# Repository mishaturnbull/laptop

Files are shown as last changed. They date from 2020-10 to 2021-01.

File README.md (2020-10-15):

# Laptop build project

* Motherboard: Udoo Bolt V8
  * Ryzen Embedded V1605B:
    * 4 core/8 thread @ 2.0GHz (max 3.6GHz)
    * Radeon Vega 8 (8 GPU CU)
* RAM: 2xDDR4 dual-channel SODIMM, upgradeable to 32GB (ECC supported)
* Supported OS: Any x86-compatible OS
  * Tested: Windows 10, Ubuntu, Kali Linux
  * Bootable from USB, onboard storage, network
* Storage:
  * 32GB eMMC onboard
  * 1x NVMe M.2 2280
  * 1x M.2 SATA 2260
  * 1x SATA 3.0 6Gb/s standard connector

# Use & reproduction permissions

This repository is licensed under the MIT license.  The only thing I ask is
that if you're going to make one, email me.  I'm curious about how many of
these machines there are going to be.

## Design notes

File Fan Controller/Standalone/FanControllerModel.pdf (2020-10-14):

%[lowC, highC, offset, scale V/C, V @ 25C] TMP35 = [10, 125, 0, .01, .25];
TMP36 = [-40, 125, 0.5, .01, .75];
TMP37 = [5, 100, 0, .02, .5];
%T = (V-offset)/scale
%range = .1 to 2V
%50 uA output. Short = 250 uA. %[Vgs(off), Vgs(on)]
FQP = [1,2.5];

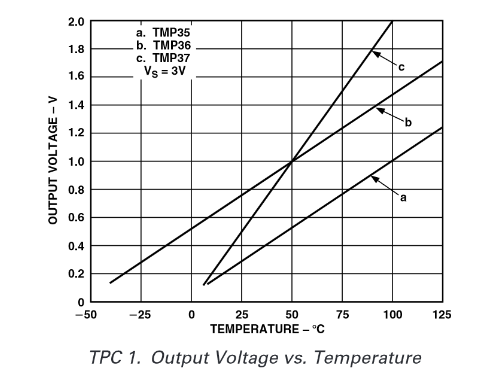
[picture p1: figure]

%TMP35:
off = (FQP(1)-TMP35(3))/TMP35(4)

off = 100
on = (FQP(2)-TMP35(3))/TMP35(4)

on = 250

%TMP36:
off = (FQP(1)-TMP36(3))/TMP36(4)

1

off = 50
on = (FQP(2)-TMP36(3))/TMP36(4)

on = 200

%TMP37:
off = (FQP(1)-TMP37(3))/TMP37(4)

off = 50
on = (FQP(2)-TMP37(3))/TMP37(4)

on = 125

2

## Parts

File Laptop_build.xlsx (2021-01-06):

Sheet: Parts
Part | Name | Link | Price per | Quantity | Price total | Power draw (A) | Power supply (V) | Watt total | Weight (g) | Weight total
Motherboard | Udoo Bolt V8 | https://www.udoo.org/udoo-bolt/ | $418.00 | 1 | $418.00 | 3.15 | 19 | 59.85 | 117 | 117
RAM 16GB | Crucial 8GBx2 2400MHz | https://www.amazon.com/Crucial-16GBx2-PC4-19200-SODIMM-260-Pin/dp/B019FRDAY6?s=gateway | $63.99 | 1 | $63.99 |  | 1.2 | 0 | 18.14 | 18.14
SSD 1TB | Crucial P1 | https://www.amazon.com/Crucial-1TB-NAND-NVMe-PCIe/dp/B07J2Q4SWZ?s=gateway | $99.95 | 1 | $99.95 | 1.7 | 3.3 | 5.61 | 18.14 | 18.14
HDD 1TB | Toshiba MQ01ABD | https://www.amazon.com/dp/B009AYVNMQ/?coliid=I35V6HECAOKQSW&colid=2LUIJZIICRMNA | $43.99 | 1 | $43.99 | 5 | 1 | 5 | 9.07 | 9.07
2KVM | 2 Port KVM HDMI | https://www.amazon.com/dp/B00FSARCX0/?coliid=I16WQOKDSD9YRY&colid=2LUIJZIICRMNA | $76.19 | 1 | $76.19 |  |  | 0 | 12.6 | 12.6
Qwiic cable kit | Qwiic cable kit | https://www.amazon.com/Electronics123-SparkFun-Qwiic-Cable-Kit/dp/B07ML9BMXX?s=gateway | $15.35 | 1 | $15.35 | 0 | 0 | 0 |  | 0
Fingerprint reader | SF 14518 | https://www.amazon.com/dp/B07BHPZL11/?coliid=I1FC7WEQA7ZYF9&colid=2LUIJZIICRMNA | $38.95 | 1 | $38.95 |  |  | 0 | 18.14 | 18.14
10DoF IMU | MPU9250+BMP180 | https://wiki.seeedstudio.com/Grove-IMU_10DOF/ | $16.90 | 1 | $16.90 | 0.00393 | 3.3 | 0.012969 |  | 0
GNSS | SAM-M8Q Breakout | https://www.sparkfun.com/products/15210 | $39.95 | 1 | $39.95 | 0.029 | 3.3 | 0.0957 |  | 0
Battery packs | 5Ah 11.1V 3S LiPo x2 | https://www.amazon.com/dp/B072WQ6FNP/?coliid=I3MOC6L9HG307I&colid=2LUIJZIICRMNA | $74.89 | 2 | $149.78 |  |  | 0 | 753 | 1506
Protoboard pack | 32pc 2-side PCB proto | https://www.amazon.com/ELEGOO-Prototype-Soldering-Compatible-Arduino/dp/B072Z7Y19F?s=industrial | $9.99 | 1 | $9.99 | 0 | 0 | 0 |  | 0
Breadboard pack | Breadboard + zipwire | https://www.amazon.com/BreadBoard-ZipWire-Solderless-ZW-MM-10-ZipWires/dp/B00PKKPSCU?s=industrial | $8.90 | 1 | $8.90 | 0 | 0 | 0 |  | 0
USB3 Hub | Anker 4-port | https://www.amazon.com/Anker-Extended-MacBook-Surface-Notebook/dp/B07L32B9C2?s=gateway | $7.99 | 1 | $7.99 | 0 | 0 | 0 | 18.14 | 18.14
Keyboard | Periboard-426 | https://www.amazon.com/gp/product/B087679W1N?psc=1 | $19.99 | 1 | $19.99 | 0.3 | 5 | 1.5 | 381 | 381
Numpad | DFMicro USB Numpad | https://www.amazon.com/gp/product/B0872XMZ4M?psc=1 | $7.99 | 1 | $7.99 | 0.25 | 5 | 1.25 | 120 | 120
Touchpad | Keymecher Mano | https://www.amazon.com/Keymecher-Multi-Gesture-Trackpad-Touchpad-Precision/dp/B085SVLH95 | $39.99 | 1 | $39.99 |  | 5 | 0 | 91 | 91
Screen 15.6in | ZSCMALLS 15.6” | https://www.amazon.com/ZSCMALLS-Portable-Computer-Nintendo-Raspberry/dp/B07VFF4TZG | $129.99 | 1 | $129.99 | 3 | 5 | 15 | 644 | 644
USB-C cable | USB-C 1.5ft x2 | https://www.amazon.com/Besgoods-Charging-Braided-Compatible-Nintendo/dp/B07H24V7YJ?s=pc | $8.59 | 1 | $8.59 | 0 | 0 | 0 | 40.82 | 40.82
WiFi/BT | Kit M.2 WiFi/Bt | https://shop.udoo.org/kit-m2-wifi-bt.html | $16.90 | 1 | $16.90 |  |  | 0 | 8.5 | 8.5
USB-C extension | USB-C 3.1 extension x2 | https://www.amazon.com/RIITOP-Extender-Extension-Nintendo-Macbook/dp/B07NSXGM7F?s=aht | $15.99 | 1 | $15.99 | 0 | 0 | 0 | 22.7 | 22.7
Ethernet extension | 1ft patch cable | https://www.amazon.com/Monoprice-Flexboot-Ethernet-Patch-Cable/dp/B00AJHCMG4?s=gateway | $2.22 | 1 | $2.22 | 0 | 0 | 0 | 18.14 | 18.14
Ethernet coupler | RJ45 coupler 10Gb | https://www.amazon.com/Haitronic-ethernet-Connector-Ethernet-Extender/dp/B06XPZBRJ2/136-8664393-2449817 | $6.99 | 1 | $6.99 | 0 | 0 | 0 | 22.7 | 22.7
Cooling fan | Mini 5V cooling fan | https://www.adafruit.com/product/3368 | $3.50 | 3 | $10.50 | 0.2 | 5 | 3 | 6.2 | 18.6
Temperature sensor | TMP36 | https://www.digikey.com/en/products/detail/analog-devices-inc/TMP36GT9Z/820404 | $1.48 | 4 | $5.92 | 0.0001 | 5 | 0.002 |  | 0
Total |  |  |  | 30 | $1255.00 | 13.63303 | 19 | 91.320669 |  | 3084.69

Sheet: Cooling
Fluid options
Brand | Name | Thermal Cap
3M | Fluorinert |  | https://multimedia.3m.com/mws/media/1783283O/data-center-immersion-cooling-aplications-with-3m-fluorinert-electronic-liquids-line-card.pdf
3M | Novec |  | https://multimedia.3m.com/mws/media/1801351O/data-center-immersion-cooling-aplications-with-3m-novec-engineered-fluids-line-card.pdf
Xoxide | PC-ICE |  | http://www.xoxide.com/primoice-nonconductive-fluid-clear.html
NA | distilled water | 4
NA | mineral oil | 1.6

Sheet: BatteryReqs
Per Battery Pack |  |  |  | N. Battery Packs |  | Power system available |  |  | Life expectancy
N. 18650 | 8 | Output V | 14 | Series | 1 | Total Wh | 154 |  | Power draw (from Parts sheet), W | 84.319169
V/cell | 3.5 | Max A | 5.5 | Parallel | 2 | Total mAh | 11000 |  | Time to death (h) | 1.826393711
mAh/cell | 2750 | Max W | 77 |  |  | Input V | 14 |  | Available power (W) | 154
Series | 4 | mAh | 5500 |  |  | Max A | 11
Parallel | 2 | Wh | 77
C rating | 1
 |  |  |  |  |  | Watt-amp avail & draw
 |  |  |  |  |  | Rail voltage | Avail (A) | Draw (A) | Draw (W)
 |  |  |  |  |  | 3.3 | 46.66666667 | 1.73293 | 5.718669
 |  |  |  | Only input on this color! |  | 5 | 30.8 | 3.7501 | 18.7505
 |  |  |  |  |  | 19 | 8.105263158 | 3.15 | 59.85
 |  |  | WARNING: THIS SPREADSHEET IS LIKELY WRONG. I am not an electrical engineer, and it has not (yet) been looked over by one! Some of the formulas are KNOWN TO BE INCORRECT!

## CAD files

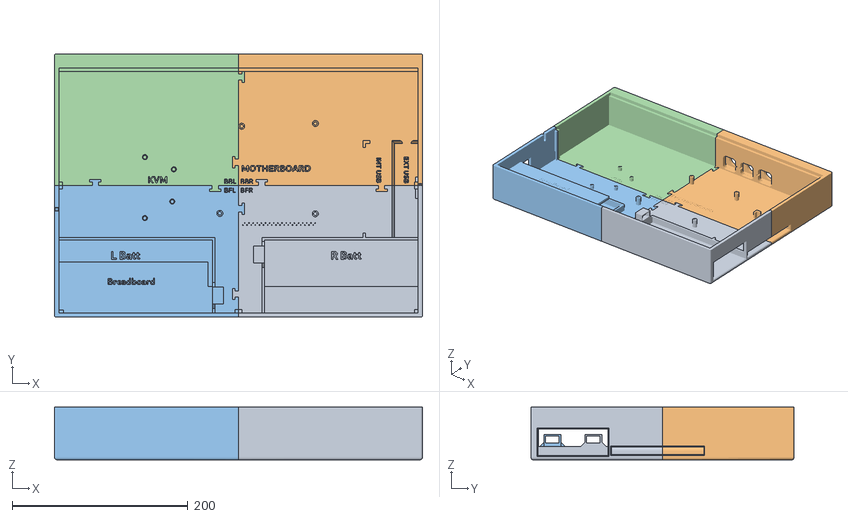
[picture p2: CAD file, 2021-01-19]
cad/case.obj
419.0 x 300.0 x 60.0
bottom-front-right
bottom-back-right
bottom-front-left
bottom-back-left

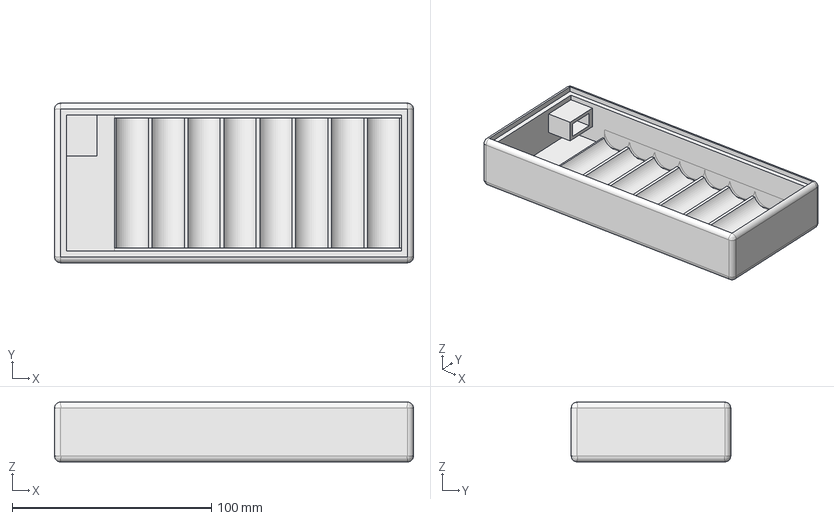
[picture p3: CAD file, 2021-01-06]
cad/battpack.FCStd
180.0 x 80.0 x 30.0 mm

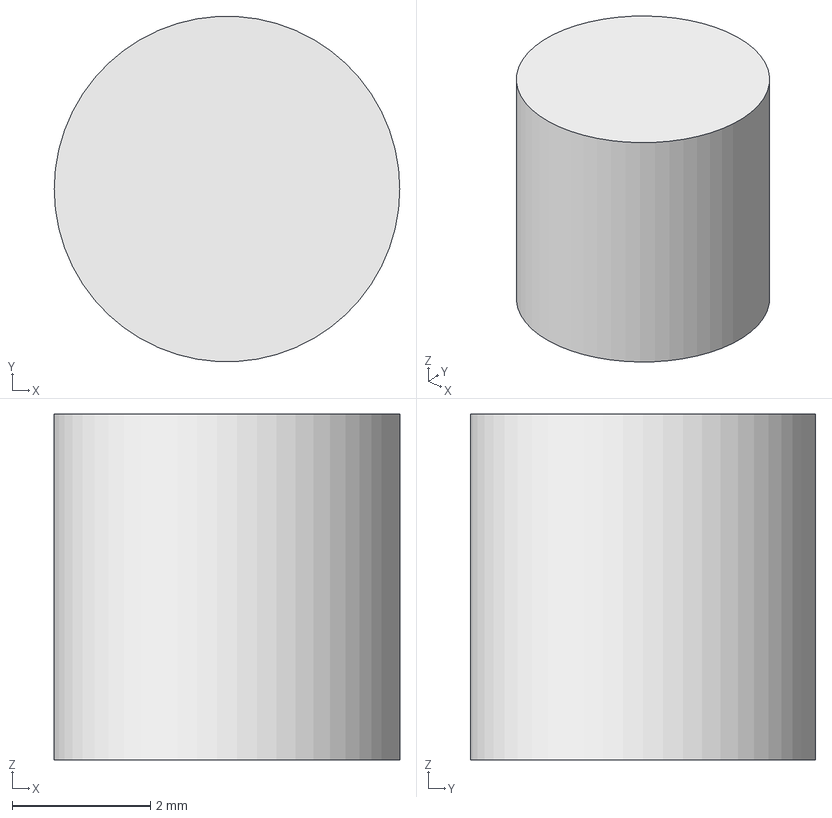
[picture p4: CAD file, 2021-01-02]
cad/vert-hold-pin-2.FCStd
5.00 x 4.99 x 5.00 mm

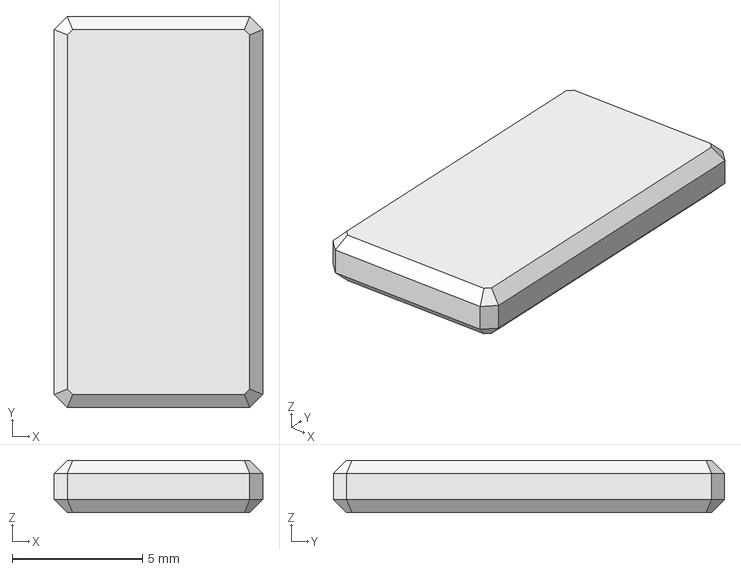
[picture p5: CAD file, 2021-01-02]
cad/vert-hold-pin-1.FCStd
8.00 x 15.0 x 2.00 mm

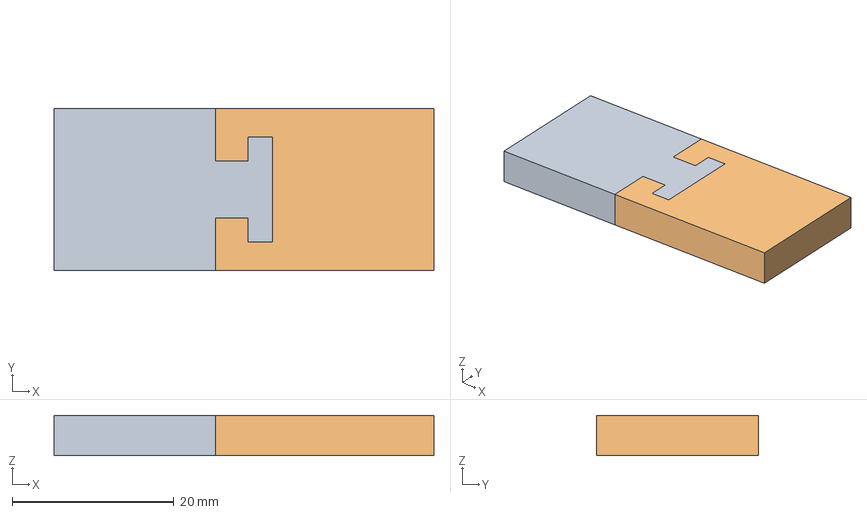
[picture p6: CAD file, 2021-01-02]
cad/tjoint-strength-test.FCStd
47.0 x 20.0 x 5.00 mm
male
female

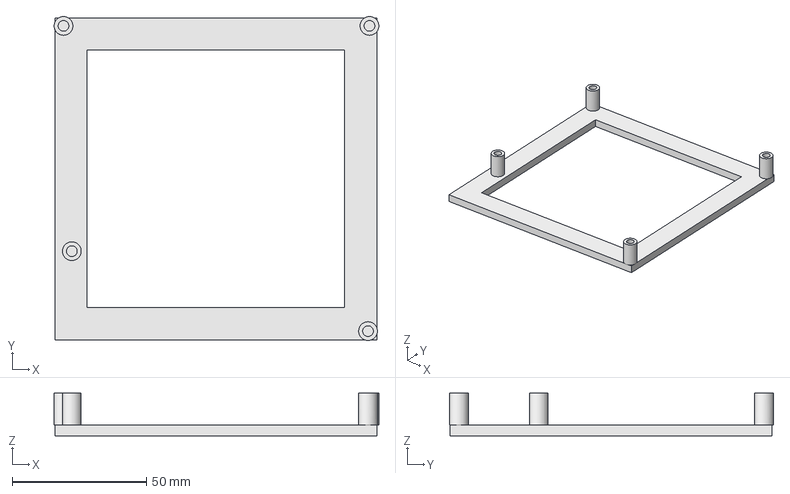
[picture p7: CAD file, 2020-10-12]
cad/caseless-bolt-holder.FCStd
121.0 x 120.8 x 16.0 mm

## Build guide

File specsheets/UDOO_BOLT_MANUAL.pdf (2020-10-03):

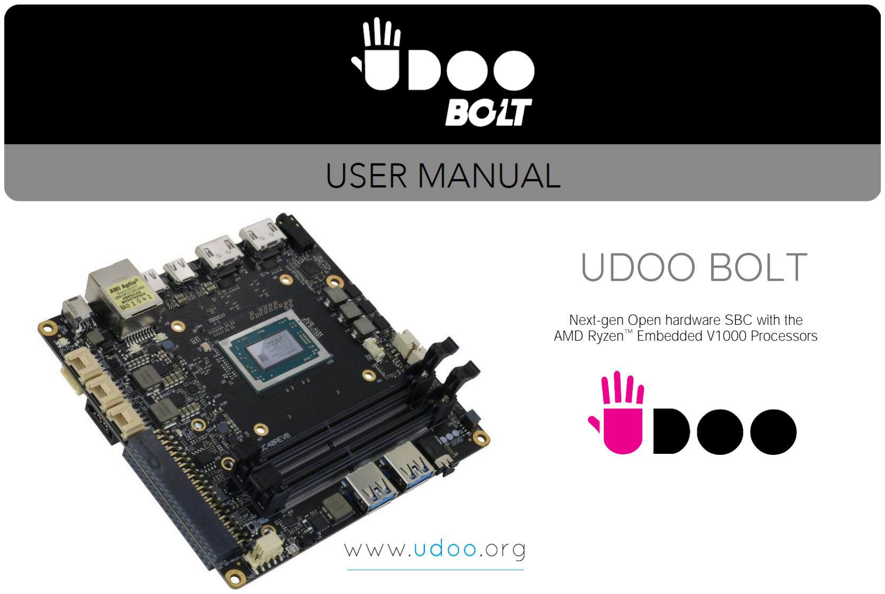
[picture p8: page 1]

# UDOO BOLT

### Next-gen Open hardware SBC with the AMD Ryzen Embedded V1000 Processors

## BOLT

UDOO BOLT User Manual - Rev. First Edition: 1.0 - Last Edition: 1.0 - Author: S.B. - Reviewed by L.V. Copyright © 2019 SECO S.p.A. | 2

This manual is released under Creative Commons Attribution-NonCommercial-ShareAlike 4.0 International (CC BY-NC-SA 4.0) license (https://creativecommons.org/licenses/by-nc-sa/4.0/)
Every effort has been made to ensure the accuracy of this manual. However, SECO S.p.A. accepts no responsibility for any inaccuracies, errors or omissions herein. SECO S.p.A. reserves the right to change precise specifications without prior notice to supply the best product possible.
To get the required assistance for any and possible issues, please contact us using the dedicated web form available at http://www.udoo.org/customer-care/open.php. (http://www.udoo.org/customer-care/open.php)
Our team is ready to assist.
Revision | Date | Note | Ref
1.0 | 19 April 2019 | First Official Release. | SB
1.1 | 11 September 2019

Matching between commercial names and ordering codes added; Safety and certifications paragraph 1.4 updated
Labels paragraph 1.7 added
Typo corrected in par. 4.6

SB

## REVISION HISTORY

Throughout all this document the commercial names: UDOO BOLT V3 and UDOO BOLT V8 will refer, respectively, to the ordering codes P/N SC40-1000-0000-C0 and SC40-2000-0000-C0 will be called with

UDOO BOLT User Manual - Rev. First Edition: 1.0 - Last Edition: 1.0 - Author: S.B. - Reviewed by L.V. Copyright © 2019 SECO S.p.A. | 3

## INDEX

UDOO BOLT User Manual - Rev. First Edition: 1.0 - Last Edition: 1.0 - Author: S.B. - Reviewed by L.V. Copyright © 2019 SECO S.p.A. | 4

UDOO BOLT User Manual - Rev. First Edition: 1.0 - Last Edition: 1.0 - Author: S.B. - Reviewed by L.V. Copyright © 2019 SECO S.p.A. | 5

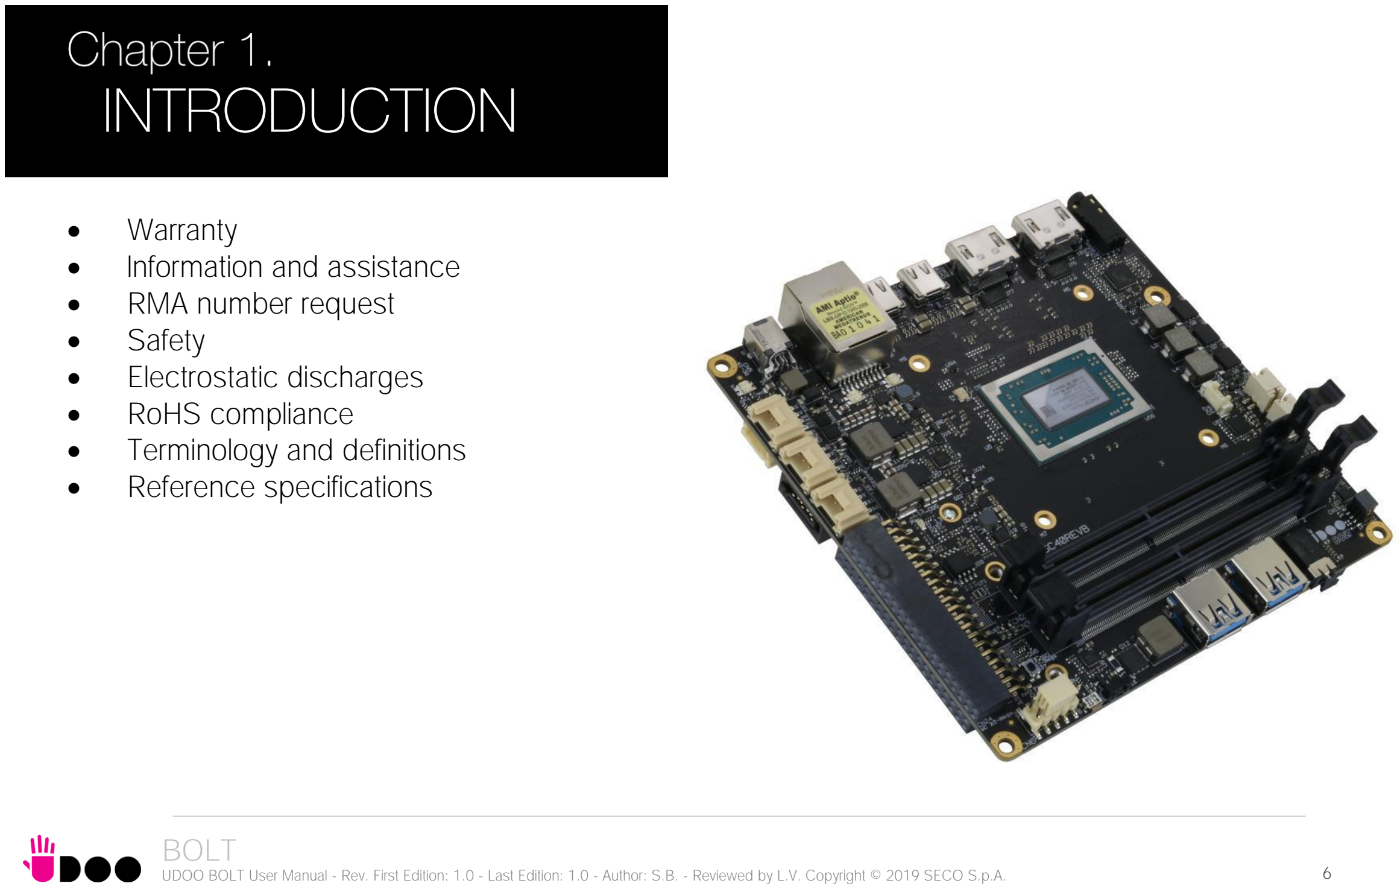
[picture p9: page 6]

UDOO BOLT User Manual - Rev. First Edition: 1.0 - Last Edition: 1.0 - Author: S.B. - Reviewed by L.V. Copyright © 2019 SECO S.p.A. | 6

## - Warranty - Information and assistance - RMA number request - Safety - Electrostatic discharges - RoHS compliance - Terminology and definitions - Reference specifications

UDOO BOLT User Manual - Rev. First Edition: 1.0 - Last Edition: 1.0 - Author: S.B. - Reviewed by L.V. Copyright © 2019 SECO S.p.A. | 7

## 1.1 Warranty

This product is subject to the Italian Law Decree 24/2002, acting European Directive 1999/44/CE on matters of sale and warranties to consumers.
The warranty on this product lasts for 2 years.
Under the warranty period, the Supplier guarantees the buyer assistance and service for repairing, replacing or credit of the item, at the Supplier’s own discretion. Items cannot be returned unless previously authorized by the supplier.
The authorization is released after completing the specific form available on the web-site http://www.udoo.org/customer-care/ (Open a New Ticket → Return Merchandise Application). The RMA authorization number must be put both on the packaging and on the documents shipped with the items, which must include all the accessories in their original packaging, with no signs of damage to, or tampering with, any returned item.
The error analysis form identifying the fault type must be completed by the customer and has must accompany the returned item.
Following a technical analysis, the supplier will verify if all the requirements, for which a warranty service applies, are met. If the warranty cannot be applied, the Supplier will calculate the minimum cost of this initial analysis on the item and the repair costs. Costs for replaced components will be calculated separately.

All changes or modifications to the equipment not explicitly approved by SECO S.p.A. could impair the equipment’s functionalities and could

UDOO BOLT User Manual - Rev. First Edition: 1.0 - Last Edition: 1.0 - Author: S.B. - Reviewed by L.V. Copyright © 2019 SECO S.p.A. | 8

## 1.2 Information and assistance

What do I have to do if I’m experiencing problems with my product?

The following services are available:
- UDOO website: visit http://www.udoo.org to receive the latest information on the product. In most cases it is possible to find useful information to solve the problem.
- UDOO Forum: join to the community of UDOO users. In the forum, available at http://www.udoo.org/forum/, it is possible to search the multiple topics of the community, and look for other users that had the same kind of problem - and how they solved it. It is also possible to post new topics to ask for specific help.
- Repair centre: it is possible to send the faulty product to the SECO Repair Centre. In this case, follow this procedure:
- Returned items must be accompanied by a RMA Number. Items sent without the RMA number will be not accepted.
- Returned items must be shipped in an appropriate package. SECO is not responsible for damages caused by accidental drop, improper usage, or customer neglect.
Note: Please have the following information before asking for technical assistance:
- Name and serial number of the product;
- Description of Customer’s peripheral connections;
- Description of Customer’s software (operating system, version, application software, etc.);
- A complete description of the problem;
- The exact words of every kind of error message encountered.

## 1.3 RMA number request

To request a RMA number, please visit UDOO web-site. On the bottom of the page, please select “Customer Care”, click on the “Open a New ticket” button and. A RMA Number will be sent within 1 working day (only for on-line RMA requests).

UDOO BOLT User Manual - Rev. First Edition: 1.0 - Last Edition: 1.0 - Author: S.B. - Reviewed by L.V. Copyright © 2019 SECO S.p.A. | 9

## 1.4 Safety and certifications

The UDOO BOLT board uses only extremely-low voltages.
While handling the board, please use extreme caution to avoid any kind of risk or damages to electronic components.

CE and FCC certification retained using only the UDOO BOLT qualified Power Supply Unit. When not using UDOO BOLT qualified Power Supply, use 19VDC (min 60W power) PSUs certified for your country (make sure that the power cable is less than 3 mt. long).
UDOO BOLT qualified PSU: YS50-1903150. Input: 100-240VAC 50/60Hz. Output: 19VDC 3.15A 65WMax
CE and FCC certifications retained with the board inside the UDOO BOLT metal case. When not available, it is suggested to use a case with the same attributes as the UDOO BOLT metal Case (P/N: ENCLOSURE_BOLT).
The UDOO BOLT V3 (P/N: SC40-1000-0000-C0) and UDOO BOLT V8 (P/N SC40-2000-0000-C0) are part of the KIT_UDOO_BOLT_V3 and KIT_UDOO_BOLT_V8 can be sold individually as a spare part allowing the end user to replace the board inside the Enclosure.

## 1.5 Electrostatic discharges

The UDOO BOLT board, like any other electronic product, is an electrostatic sensitive device: high voltages caused by static electricity could damage some or all the devices and/or components on-board.

This product should be operated in a well-ventilated environment and, if used inside a case, the case should not be covered.
This product should be elevated on a stable, flat, electrically non-conductive surface whilst in operation, and clear from any object that can induce a short-circuit.
Do not expose it to water, moisture or heat from any source; UDOO BOLT is designed for reliable operation at normal ambient room temperatures.
Avoid handling the warm and moving parts (like the fan) and generally the printed circuit board while it is powered

Only handle by the edges to minimise the risk of electrostatic discharge damage.
Take care whilst handling to avoid mechanical or electrical damage to the printed circuit board and connectors. Also use a grounded wrist strap or touch a safely grounded object before you handle components.

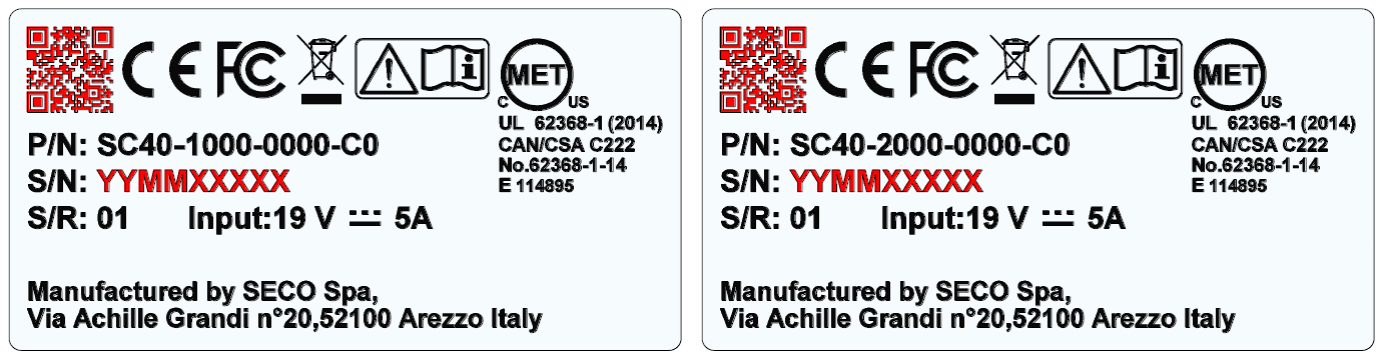
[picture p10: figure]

UDOO BOLT User Manual - Rev. First Edition: 1.0 - Last Edition: 1.0 - Author: S.B. - Reviewed by L.V. Copyright © 2019 SECO S.p.A. | 10

## 1.6 RoHS compliance

The UDOO BOLT board is designed using RoHS compliant components and is manufactured on a lead-free production line. It is therefore fully RoHS compliant.

## 1.7 Labels

The labels above depend on the board: the left one is related to the module UDOO_BOLT_V3 (P/N: SC40-1000-0000-C0) while the right label is related to the module UDOO_BOLT_V8 (P/N: SC40-2000-0000-C0).
The parts highlighted in red (the QR Code and the Serial Number) will change for every Board.
The S/N is divided in:
YY= Year of Manufacturing.
MM= Month of Manufacturing. XXXXX= Monthly Progressive Number

UDOO BOLT User Manual - Rev. First Edition: 1.0 - Last Edition: 1.0 - Author: S.B. - Reviewed by L.V. Copyright © 2019 SECO S.p.A. | 11

## 1.8 FCC certification

This device complies with part 15 of the FCC Rules. Operation is subject to the following two conditions:
(1) This device may not cause harmful interference, and
(2) this device must accept any interference received, including interference that may cause undesired operation.
This equipment has been tested and found to comply with the limits for a Class B digital device, pursuant to part 15 of the FCC Rules. These limits are designed to provide reasonable protection against harmful interference in a residential installation. This equipment generates, uses and can radiate radio frequency energy and, if not installed and used in accordance with the instructions, may cause harmful interference to radio communications. However, there is no guarantee that interference will not occur in a particular installation. If this equipment does cause harmful interference to radio or television reception, which can be determined by turning the equipment off and on, the user is encouraged to try to correct the interference by one or more of the following measures:
Reorient or relocate the receiving antenna.
Increase the separation between the equipment and receiver.
Connect the equipment into an outlet on a circuit different from that to which the receiver is connected. Consult the dealer or an experienced radio/TV technician for help.

To comply with FCC RF exposure compliance requirements, a separation distance of at least 20 cm must be maintained between th e antenna of this device and all nearby persons.

FCC certification retained using only the UDOO BOLT qualified Power Supply Unit (19V Brick Power Adapter). When not using UDOO BOLT qualified Power Supply, use 19VDC (min 60W power) PSUs certified for your country (make sure that the power cable is less than 3 mt. long).

SECO S.p.A.
Model: UDOO BOLT V3; UDOO BOLT V8

Changes or modifications not expressly approved by the party responsible for compliance could void the user’s authority to operate the

UDOO BOLT User Manual - Rev. First Edition: 1.0 - Last Edition: 1.0 - Author: S.B. - Reviewed by L.V. Copyright © 2019 SECO S.p.A. | 12

## 1.9 ISED certification

This device complies with Industry Canada licence-exempt RSS standard(s). Operation is subject to the following two conditions:
(1) This device may not cause interference
(2) this device must accept any interference, including interference that may cause undesired operation of the device.

Le présent appareil est conforme aux CNR d’Industrie Canada applicables aux appareils radio exempts de licence. L’exploitation est autorisée aux deux conditions suivantes:
(1) l’appareil ne doit pas produire de brouillage, et
(2) l’utilisateur de l’appareil doit accepter tout brouillage radioélectrique subi, même si le brouillage est susceptible d’en compromettre le fonctionnement.
Ce dispositif a été conçu pour fonctionner avec les antennes fournies avec ce produit. L’utilisation d’autres antennes peut enfreindre les règles industrielles du Canada et annuler l’autorité de l’utilisateur quant au fonctionnement de l’équipement.

This device complies with RSS-210, ICES-3(B)/NMB-3(B)

UDOO BOLT User Manual - Rev. First Edition: 1.0 - Last Edition: 1.0 - Author: S.B. - Reviewed by L.V. Copyright © 2019 SECO S.p.A. | 13

## 1.10 Terminology and definitions

ACPI | Advanced Configuration and Power Interface, an open industrial standard for the board’s devices configuration and power management
AHCI | Advanced Host Controller Interface, a standard which defines the operation modes of SATA interface
API | Application Program Interface, a set of commands and functions that can be used by programmers for writing software for specific Operating Systems
BIOS | Basic Input / Output System, the Firmware Interface that initializes the board before the OS starts loading
CEC | Consumer Electronics Control, an HDMI feature which allows controlling more devices connected together by using only one remote control
DDC | Display Data Channel, a kind of I2C interface for digital communication between displays and graphics processing units (GPU)
DDR | Double Data Rate, a typology of memory devices which transfer data both on the rising and on the falling edge of the clock
DDR4 | DDR, 4 th generation
EC | Embedded Controller
GbE | Gigabit Ethernet
Gbps | Gigabits per second
GND | Ground
GPI/O | General purpose Input/Output
HD Audio | High Definition Audio, most recent standard for hardware codecs developed by Intel® in 2004 for higher audio quality
HDMI | High Definition Multimedia Interface, a digital audio and video interface
I2C Bus | Inter-Integrated Circuit Bus, a simple serial bus consisting only of data and clock line, with multi-master capability
M.2 | Specifications for internal expansion modules, which defines many pinouts and sizes for different purposes. Can include SATA, PCI Express, USB, UART, DP interfaces
Mbps | Megabits per second
MMC/eMMC | MultiMedia Card / embedded MMC, a type of memory card, having the same interface as the SD card. The eMMC is the embedded version of the MMC. They are devices that incorporate the flash memories on a single BGA chip.
N.A. | Not Applicable
N.C. | Not Connected
OpenCL | Open Computing Language, a software library based on C99 programming language, conceived explicitly to realise parallel computing using Graphics Processing Units (GPU)
OpenGL | Open Graphics Library, an Open Source API dedicated to 2D and 3D graphics
OS | Operating System

UDOO BOLT User Manual - Rev. First Edition: 1.0 - Last Edition: 1.0 - Author: S.B. - Reviewed by L.V. Copyright © 2019 SECO S.p.A. | 14
PCI-e | Peripheral Component Interface Express
PSU | Power Supply Unit
PWM | Pulse Width Modulation
PWR | Power
PXE | Preboot Execution Environment, a way to perform the boot from the network ignoring local data storage devices and/or the installed OS
SATA | Serial Advance Technology Attachment, a differential full duplex serial interface for Hard Disks
SD | Secure Digital, a memory card type
SDHC | Secure Digital Host Controller
SDIO | Secure Digital Input/Output, an evolution of the SD standard that allows the use of the same SD interface to drive different Input/Output devices, like cameras, GPS, Tuners and so on
SM Bus | System Management Bus, a subset of the I2C bus dedicated to communication with devices for system management, like a smart battery and other power supply-related devices
SPI | Serial Peripheral Interface, a 4-Wire synchronous full-duplex serial interface which is composed of a master and one or more slaves, individually enabled through a Chip Select line
TBM | To Be Measured
TDP | Thermal Design Power, an indication of the amount of heat generated by the processor that must be used for the design of the thermal solution.
TMDS | Transition-Minimized Differential Signaling, a method for transmitting high speed serial data, normally used on DVI and HDMI interfaces
UEFI | Unified Extensible Firmware Interface, a specification defining the interface between the OS and the board’s firmware. It is meant to replace the original BIOS interface
UMA | Unified Memory Architecture, synonym of Integrated Graphics, uses a portion of a computer’s system RAM dedicated to graphics rather than using dedicated graphics memory only.
USB | Universal Serial Bus
V_REF | Voltage reference Pin
xHCI | eXtensible Host Controller Interface, Host controller for USB 3.0 ports, which can also manage USB 2.0 and USB1.1 ports

UDOO BOLT User Manual - Rev. First Edition: 1.0 - Last Edition: 1.0 - Author: S.B. - Reviewed by L.V. Copyright © 2019 SECO S.p.A. | 15

## 1.11 Reference specifications

Here below it is a list of applicable industry specifications and reference documents.
Reference | Link
ACPI | http://www.acpi.info
AHCI | http://www.intel.com/content/www/us/en/io/serial-ata/ahci.html
DDC | http://www.vesa.org
Gigabit Ethernet | http://standards.ieee.org/about/get/802/802.3.html
HD Audio | http://www.intel.com/content/dam/www/public/us/en/documents/product-specifications/high-definition-audio-specification.pdf
HDMI | http://www.hdmi.org/index.aspx
I2C | http://www.nxp.com/documents/other/UM10204_v5.pdf
Intel® Front Panel I/O connectivity DG | http://www.formfactors.org/developer/specs/A2928604-005.pdf
M.2 | http://pcisig.com/specifications
MMC/eMMC | http://www.jedec.org/committees/jc-649
OpenCL | http://www.khronos.org/opencl
OpenGL | http://www.opengl.org
PCI Express | http://www.pcisig.com/specifications/pciexpress
SATA | https://www.sata-io.org
SD Card Association | https://www.sdcard.org/home
SM Bus | http://www.smbus.org/specs
TMDS | http://www.siliconimage.com/technologies/tmds
UEFI | http://www.uefi.org
USB 2.0 and USB OTG | http://www.usb.org/developers/docs/usb_20_070113.zip
USB 3.0 | http://www.usb.org/developers/docs/usb_30_spec_070113.zip
xHCI | http://www.intel.com/content/www/us/en/io/universal-serial-bus/extensible-host-controler-interface-usb-xhci.html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
AMD Ryzen Embedded V1000 | https://www.amd.com/en/products/embedded-ryzen-v1000-series

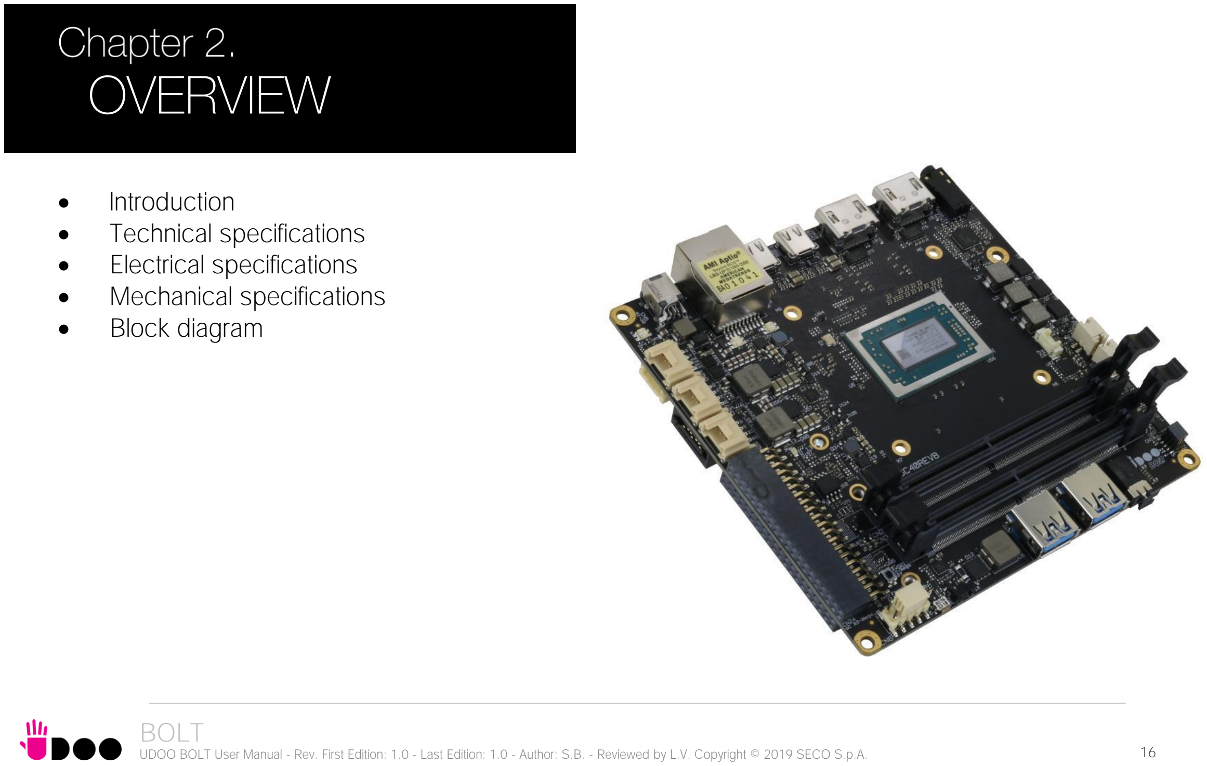
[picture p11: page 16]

UDOO BOLT User Manual - Rev. First Edition: 1.0 - Last Edition: 1.0 - Author: S.B. - Reviewed by L.V. Copyright © 2019 SECO S.p.A. | 16

## - Introduction - Technical specifications - Electrical specifications - Mechanical specifications - Block diagram

UDOO BOLT User Manual - Rev. First Edition: 1.0 - Last Edition: 1.0 - Author: S.B. - Reviewed by L.V. Copyright © 2019 SECO S.p.A. | 17

## 2.1 Introduction

The UDOO BOLT is a portable, breakthrough supercomputer that goes up to 3.6 GHz thanks to the brand-new AMD Ryzen Embedded V1000 SoC, a top-notch, multicore CPU with a powerful mobile GPU - AMD Radeon Vega 8 or AMD Radeon Vega 3 Graphics, the most incredible GPUs ever seen on a maker platform and an Arduino Leonardo compatible platform, all wrapped into one.
The UDOO BOLT can mount a Dual-Core Quad-Thread or a Quad-Core eight-thread SoCs, base frequency 2.3 or 2.0 GHz, Turbo boost at 3.2 or 3.6 GHz, with 64-bit instruction set and very low TDP. This single chip solution includes the memory controller, which gives support for up to 32GB of DDR4 memory on two SO-DIMM Slots, also capable of supporting ECC memory.
All SoCs embed an AMD Radeon Vega Graphics controller, with 3 or 8 Execution units, which offers extremely high graphical performances, supporting also High Dynamical range (HDR) Imaging. DirectX® 12, EGL 1.4, OpenCL 2.1, OpenGL® ES 1.1/ 2.x / 3.x (Halti), OpenGL® Next (Vulkan®

), OpenGL® 4.6 are also supported by this GPU, which can also offer H.265 10-bit video decoding and 8-bit encoding.
Finally, this embedded GPU is able to drive four 4K independent displays, by using the HDMI and the USB-C interfaces available.
Other features offered by the AMD Ryzen Embedded V1000 SoCs, and included in UDOO BOLT board, are two SATA Revision 3.0 Channels (one used for the common SATA / SSD drives, the other used to implement a M.2 Socket 2 Key B SSD slot), six USB ports (two USB 3.1 on standard Type-A sockets, two USB 3.1 on standard type-C sockets supporting Display Port Alternate Mode and Power Delivery functions, one USB 2.0 on M.2 Socket 1 Key E Connectivity slot and another USB 2.0 port used for the communications with the Atmega32u4 microcontroller), HD Audio and eight PCI Express lanes (two lanes are carried out on M.2 Socket 2 Key B SSD slot where they can be used as a single PCI-e x2 port, a PCI express lane is used for the implementation of the Gigabit Ethernet interface, ,another is available on M.2 Socket 1 Key E Connectivity Slot and four PCI-express Graphics lanes are carried to the M.2 Key M Slot for NVMe SSDs, where they can be used as a single PCI-e x 4 port).
Through the AMD Ryzen Embedded V1000 SoC’s USB interface #5 pass all the communications with the ATMEL ATmgea32u4 microcontroller, which implements the Arduino Leonardo interface: this situation reproduces exactly the situation of an external Arduino board connected to an x86 PC, with the advantages given by an integrated board solution.
All these features, combined together, make UDOO BOLT the most powerful maker board ever.
Please refer to following chapter for a complete list of all the integrated peripherals and the characteristics.

## 2.2 Technical specifications

SoC
AMD Ryzen Embedded V1605B with AMD Radeon Vega 8 Graphics, Quad Core Dual Thread @ 2.0GHz (3.6 Boost), TDP 12-25W
AMD Ryzen Embedded V1202B with AMD Radeon Vega 3 Graphics, Dual Core Dual Thread @ 2.3GHz (3.2 Boost), TDP 12-25W
Memory
2x DDR4 SO-DIMM Slots, supporting DDR4-2400 ECC and non-ECC memory Graphics
AMD Radeon Vega GPU with 8 (V1605B) or 3 (V1202B) Compute Units
4 independent displays supported
DirectX® 12, EGL1.4, OpenCL 2.1, OpenGL® ES 1.1/ 2.x / 3.x (Halti), OpenGL® Next (Vulkan®), OpenGL® 4.6 supported
H.265 (10-bit) decode and 8-bit video encode
VP9 decode
Video Interfaces
2x HDMI connector, supporting HDMI 1.4 / HDMI 2.0a
2x DP alternate mode interfaces on USB Type-C connectors Video Resolution
Up to 4K
Mass Storage
32GB eMMC 5.0 drive on-board
SATA 6Gb/s 7p M connector
M.2 Key B SATA SSD slot (Type 2242 or 2260 modules accepted) M.2 Key M NVMe Slot (PCI-e x4 Gen3 interface)
Networking
Realtek RTL811G Gigabit Ethernet controller
Gigabit Ethernet LAN interface
M.2 Key E Slot for optional Wireless modules M.2 Key B Slot for optional 2x GbEthernet

USB
2x USB 3.1 Host ports on Type-A sockets
2x USB 3.1 Host ports on Type-C sockets, with DisplayPort Alternate Mode and Power Delivery Role
1 x USB 2.0 Host port on M.2 Key E slot
PCI-Express
1 x PCI-e x2 port on M.2 Key B SSD Slot 1 x PCI-e x1 port on M.2 Key E slot
1 x PCI-e x4 port on M.2 Key M Slot
Audio
HD Audio Codec Realtek ALC888S
Combo TRSS connector with Mic In and Line out support S/PDIF or additional headphone signal
2 x Speaker internal headers
Other Interfaces
I2C Grove connectors
Switch/LED Front Panel Header
CIR (Consumer InfraRed) Sensor
Arduino Leonardo compatible interface
Embedded controller I/O header with 2x UART, SPI, 2x I2C, FAN Control, Keyboard Scan or GPI/O signals
Power supply: +19VDC ± 5% DC Power Jack
USB Type-C Power In
RTC Coin cell Battery
Operating temperature: 0°C ÷ +50°C** (Commercial temperature) Dimensions: 120 x 120 mm (4.72” x 4.72”).
Supported Operating Systems:
Microsoft® Windows 10
Any Linux distribution for X86 64-bit platform

** Environmental temperature, measured using UDOO BOLT Standard

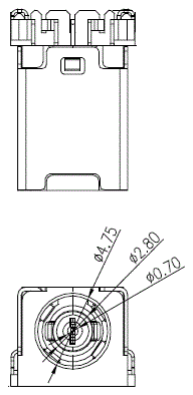
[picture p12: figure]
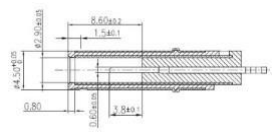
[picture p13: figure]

UDOO BOLT User Manual - Rev. First Edition: 1.0 - Last Edition: 1.0 - Author: S.B. - Reviewed by L.V. Copyright © 2019 SECO S.p.A. | 19

## 2.3 Electrical specifications

The UDOO BOLT board can be supplied only with an external 19VDC ± 5% power supply, minimum 60W (i.e. min. 3.15A @ 19V) for basic functionalities recommended. Always make sure that the power cable is less than 3mt. long.
This voltage can be supplied through a DC power jack (CN5) type Singatron p/n 2DC3122-007111F. Internal pin is VIN power line.
Mating DC plug as shown in the picture below (Singatron p/n 45P06CV230-1A00-01 or equivalent).

The Board can also be powered by using a standard USB-C power adapter, with the same minimum wattage (power profile: 20V 3A).
A bicolour Green/Yellow LED is placed near the DC IN power jack to signal the power state of the board. When the board is powered but turned off, then the LED turns on Yellow, during normal working (S0 State) the LED turns on Green light.
2.3.1 RTC Battery

For the occurrences when the module is not powered with an external power supply, on board there is a cabled coin Lithium Battery to supply, with a 3V voltage, the Real Time Clock embedded inside the AMD Ryzen Embedded V1000 SoC.
Battery used is a cabled CR2032-LD Lithium coin-cell battery, with a nominal capacity of 220mAh.

The battery is not rechargeable, and can be connected to the board using dedicated connector CN5 which is a 2-pin
p1.27 mm type MOLEX p/n 53261-0271 or equivalent, with pinout shown in the table on the left.
Mating connector: MOLEX 51021-0200 receptacle with MOLEX 50079-8000 female crimp terminals.
In case of exhaustion, the battery should only be replaced with devices of the same type. Always check the orientation before inserting and make sure that they are aligned correctly and are not damaged or leaking.
Never allow the batteries to become short-circuited during handling.

Batteries supplied with UDOO BOLT are compliant to requirements of European Directive 2006/66/EC regarding batteries and accumulators. When putting out of order UDOO BOLT, remove the batteries from the board in order to collect and dispose them according to the requirement of the same European Directive above mentioned. Even when replacing the batteries, the disposal has to be made according to these requirements.

Battery connector CN4

Pin | Signal
1 | VRTC
2 | GND

CAUTION: handling batteries incorrectly or replacing with not-approved devices may present a risk of fire or explosion.

UDOO BOLT User Manual - Rev. First Edition: 1.0 - Last Edition: 1.0 - Author: S.B. - Reviewed by L.V. Copyright © 2019 SECO S.p.A. | 20
2.3.2 | Power consumption
Using the following setup, and using all possible SoCs offered for UDOO BOLT board, the current consumption (RMS) has been measured on the VIN Power line. The board is supplied with a 19V voltage through DC power jack CN4 using a Keysight DC Power Analyzer model N6700B.
- O.S. Windows 10 Professional
- 32GB eMMC onboard
- 8GB DDR4-2133 Single Channel Memory
- USB mouse and keyboard connected
- HDMI display connected
- UEFI BIOS Release 1.00 RC 03

Status

SoC V1202B

TDP 12W | TDP 25W
| Average (120s) | Peak | Average (120s) | Peak
Idle, power saving configuration | 0.357A | 0.704A | 0.327A | 0.674A
OS Boot, power saving configuration | 0.838A | 1.388A | 0.851A | 1.450A
Video reproduction@1080p, power saving configuration | 0.712A | 0.983A | 0.722A | 1.230A
Video reproduction@4K, power saving configuration | 0.822A | 1.363A | 0.753A | 1.380A
Internal Stress Test Tool, package power set at specific TDP | 1.411A | 1.480A | 1.348A | 1.634A

UDOO BOLT User Manual - Rev. First Edition: 1.0 - Last Edition: 1.0 - Author: S.B. - Reviewed by L.V. Copyright © 2019 SECO S.p.A. | 21

Independently by the SoC mounted onboard, the following power consumptions are common to all boards:
Battery Backup power consumption: | 3.68μA
Soft-Off State power consumption: | TBM
Suspend State power consumption: | TBM
Please consider that the power consumption depends strongly on the utilization scenario. 2.3.3 Power rails naming convention

In all the tables contained in this manual, Power rails are named with the following meaning:
_RUN: Switched voltages, i.e. power rails that are active only when the board is in ACPI’s S0 (Working) state. Examples: +3.3V_RUN, +5V_RUN.
_ALW: Always-on voltages, i.e. power rails that are active both in ACPI’s S0 (Working), S3 (Standby) and S5 (Soft Off) state. Examples: +5V_ALW, +3.3V_ALW. _DSW: Deep Sleep Well voltage, i.e. power rails that remain active also when the _ALW voltages have been turned off, in a state very similar to the Mechanical Off (G3) but with the possibility of awakening of the module upon a very limited set of events. It is not supported by UDOO Bolt firmware, however.
_SUS: unswitched ACPI S3 voltages, i.e. power rails that are active both in ACPI’s S0 (Working) and S3 (Standby) state. Examples: +1.5V_SUS
Other suffixes are used for application specific power rails, which are derived from same voltage value of voltage switched rails, if it is not differently stated (for example, +5VHDMI is derived from +5V_RUN, and so on).

Status

SoC V1605B

TDP 12W | TDP 25W
| Average (120s) | Peak | Average (120s) | Peak
Idle, power saving configuration | 0.345A | 0.752A | 0.341A | 0.635A
OS Boot, power saving configuration | 0.797A | 1.608A | 0.780A | 1.899A
Video reproduction@1080p, power saving configuration | 0.666A | 1.156A | 0.593A | 1.072A
Video reproduction@4K, power saving configuration | 0.847A | 1.308A | 0.778A | 1.424A
Internal Stress Test Tool, package power set at specific TDP | 1.293A | 1.485A | 1.506A | 1.943A

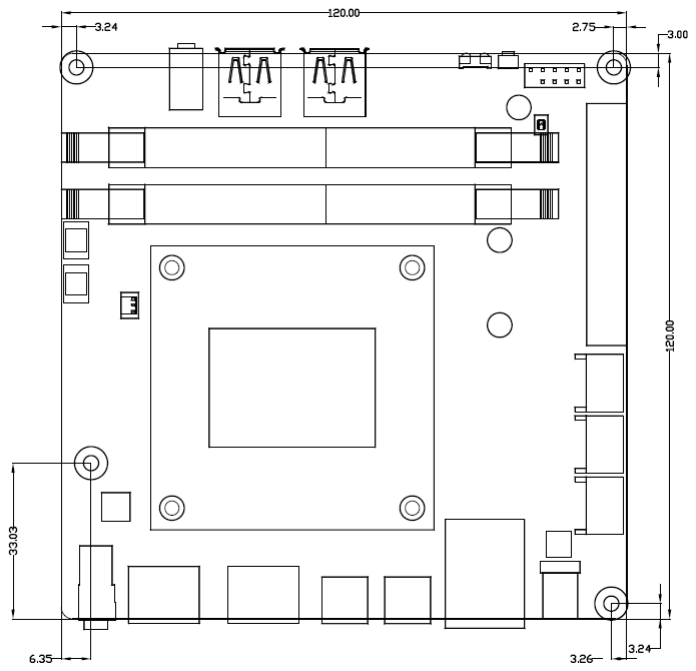
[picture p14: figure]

UDOO BOLT User Manual - Rev. First Edition: 1.0 - Last Edition: 1.0 - Author: S.B. - Reviewed by L.V. Copyright © 2019 SECO S.p.A. | 22

## 2.4 Mechanical specifications

The board dimensions are 120 x 120 mm (4.72” x 4.72”).
The printed circuit of the board is made of twelve layers, some of them are ground planes, for disturbance rejection.

## 2.5 Block diagram

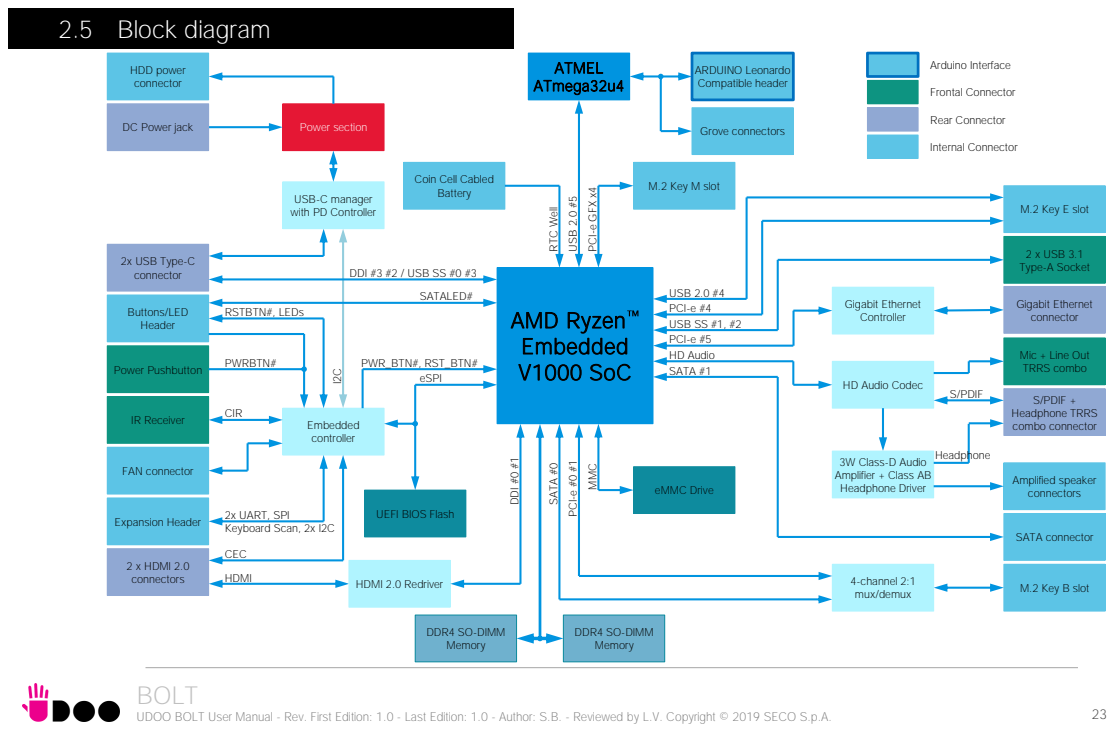
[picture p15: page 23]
UDOO BOLT User Manual - Rev. First Edition: 1.0 - Last Edition: 1.0 - Author: S.B. - Reviewed by L.V. Copyright © 2019 SECO S.p.A.; AMD Ryzen Embedded V1000 SoC; Power section; DDR4 SO-DIMM Memory; Buttons/LED Header; IR Receiver; FAN connector; 2 x HDMI 2.0 connectors; Gigabit Ethernet Controller; S/PDIF + Headphone TRRS combo connector; 2 x USB 3.1 Type-A Socket; Gigabit Ethernet connector; M.2 Key E slot; SATA connector; Embedded controller; ATMEL ATmega32u4; PCI-e #4; eSPI; CIR; CEC; HDMI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

Arduino Interface HDD power
connector

DC Power jack

Coin Cell Cabled
Battery

USB-C manager
with PD Controller

DDI #3 #2 / USB SS #0 #3

Mic + Line Out
TRRS combo

HD Audio Codec

3W Class-D Audio
Amplifier + Class AB
Headphone Driver

UEFI BIOS Flash

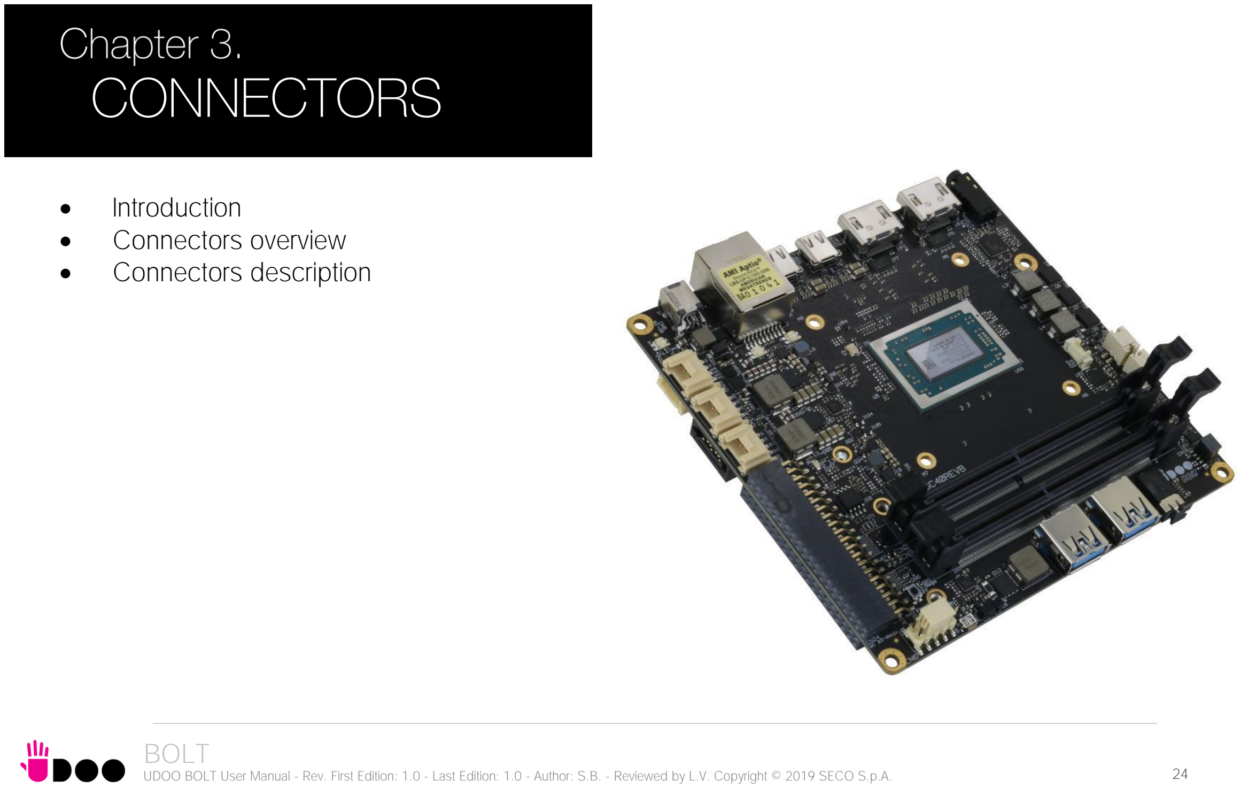
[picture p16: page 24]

UDOO BOLT User Manual - Rev. First Edition: 1.0 - Last Edition: 1.0 - Author: S.B. - Reviewed by L.V. Copyright © 2019 SECO S.p.A. | 24

## - Introduction - Connectors overview - Connectors description

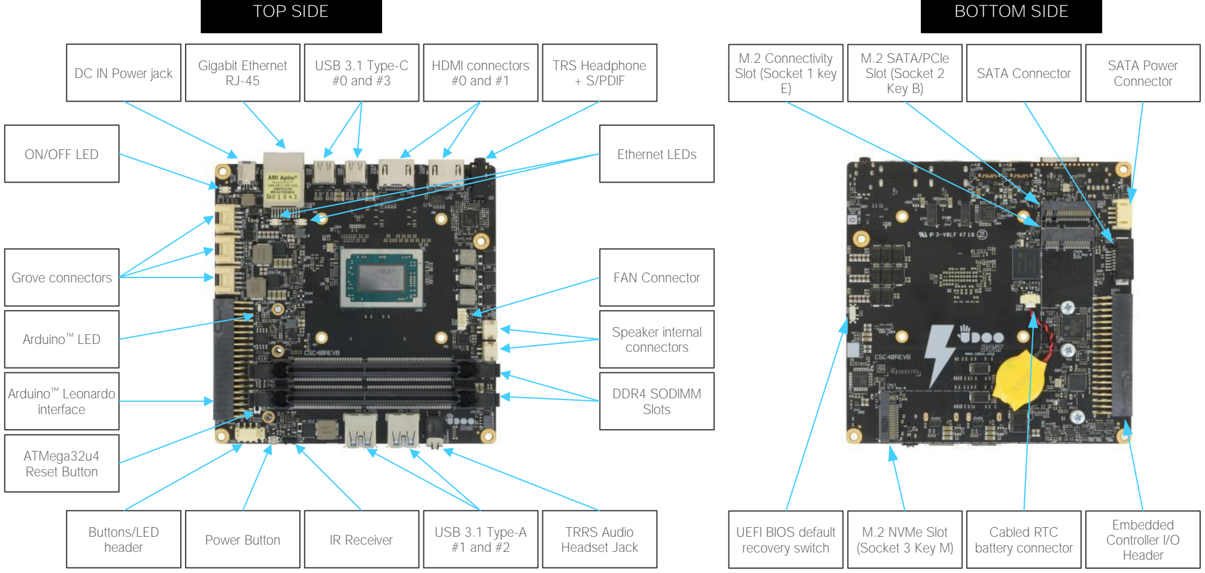
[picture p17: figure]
TOP SIDE; BOTTOM SIDE; Gigabit Ethernet RJ-45; Arduino Leonardo interface; Buttons/LED header; DDR4 SODIMM Slots; DC IN Power jack; Power Button; IR Receiver; USB 3.1 Type-A; #1 and #2; TRRS Audio Headset Jack; FAN Connector; USB 3.1 Type-C #0 and #3; HDMI connectors #0 and #1; TRS Headphone + S/PDIF; Grove connectors; Speaker internal connectors; ATMega32u4 Reset Button; Arduino LED; ON/OFF LED; Ethernet LEDs; M.2 Connectivity Slot (Socket 1 key E); M.2 SATA/PCIe Slot (Socket 2 Key B); SATA Connector; UEFI BIOS default recovery switch; M.2 NVMe Slot (Socket 3 Key M)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

UDOO BOLT User Manual - Rev. First Edition: 1.0 - Last Edition: 1.0 - Author: S.B. - Reviewed by L.V. Copyright © 2019 SECO S.p.A. | 25

## 3.1 Introduction

On UDOO BOLT board, there are several connectors located on the upper plane. Standard connectors are placed on the same sides of PCB, so that it is possible to place them on a panel of an eventual enclosure.

UDOO BOLT User Manual - Rev. First Edition: 1.0 - Last Edition: 1.0 - Author: S.B. - Reviewed by L.V. Copyright © 2019 SECO S.p.A. | 26

## 3.2 Connectors overview

Name | Description | Name | Description
CN4 | Cabled RTC Battery | CN19 | HDMI connector #1
CN5 | DC IN Power Jack | CN20 | HDMI connector #0
CN6 | Buttons/LED Internal Header | CN21 | USB 3.1 Type-A Port #1
CN7 | FAN Connector | CN22 | USB 3.1 Type-A Port #2
CN8 | USB Type-C Port #0 | CN23 | Gigabit Ethernet connector
CN9 | USB Type-C Port #3 | CN24 | Arduino Leonardo interface Connector
CN10 | USB C Controller programming header (reserved) | CN25 | Embedded Controller I/O Header
CN11 | TRRS Audio Headset Jack | CN26 | GROVE Analog Connector
CN12 | TRS Headphone + S/PDIF | CN27 | GROVE Digital / UART Connector
CN14 | SATA Port #1 M 7p connector | CN28 | GROVE I2C Connector
CN15 | SATA Power Connector | CN29 | Right Speaker Connector
CN16 | M.2 Connectivity Slot (Socket 1 Key E Type 2230) | CN30 | Left Speaker Connector
CN17 | M.2 NVMe Slot (Socket 3 Key M Type 2280) | SW1 | UEFI BIOS default Restore switch
CN18 | M.2 SATA/PCI-e Slot (Socket 2 Key B type 2242 or 2260) | U61 | IR Receiver

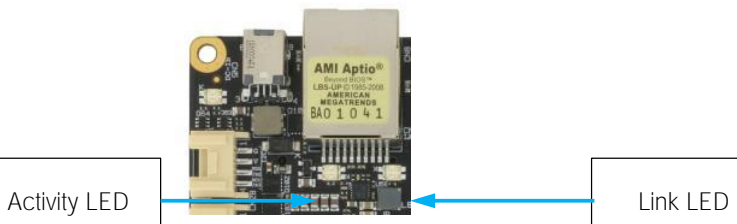
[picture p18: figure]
Activity LED; Link LED

UDOO BOLT User Manual - Rev. First Edition: 1.0 - Last Edition: 1.0 - Author: S.B. - Reviewed by L.V. Copyright © 2019 SECO S.p.A. | 27

## 3.3 Connectors description

3.3.1 Ethernet connector
On board, there is a Gigabit Ethernet connector, for the direct connection of the UDOO BOLT module to a wired LAN.
The Ethernet connection is managed by a dedicated Realtek RTL8111G
Gigabit Ethernet controller, interfaced to PCI-express port #5.
This interface is compatible both with Gigabit Ethernet (1000Mbps) and
with Fast Ethernet (10/100Mbps) Networks. They will configure automatically to work with the existing network.
Please be aware that it will work in Gigabit mode only in case that it is connected to Gigabit Ethernet switches/hubs/routers. For the connection, cables category Cat5e or better are required. Cables category Cat6 are recommended for noise reduction and EMC compatibility issues, especially when the length of the cable is significant. GBE_MDI0+/GBE_MDI0-: Ethernet Controller Media Dependent Interface (MDI) I/O differential pair #0. It is the first differential pair in Gigabit Ethernet mode, and the Transmit differential pair in 10/100 Mbps modes.
GBE_MDI1+/GBE_MDI1-: Ethernet Controller Media Dependent Interface (MDI) I/O differential pair #1. It is the second differential pair in Gigabit Ethernet mode, and the Receive differential pair in 10/100 Mbps modes.
GBE_MDI2+/GBE_MDI2-: Ethernet Controller Media Dependent Interface (MDI) I/O differential pair #2. It is the third differential pair in Gigabit Ethernet mode; it is not used in 10/100Mbps modes.
GBE_MDI3+/GBE_MDI3-: Ethernet Controller Media Dependent Interface (MDI) I/O differential pair #3. It is the fourth differential pair in Gigabit Ethernet mode; it is not used in 10/100Mbps modes.
Placed behind the GbE connector there are also two bicolour Green/Yellow LEDs: LED D159 (Right LED) shows 10/100 or 1000 connection: green means 100Mbps connection, yellow means 1000Mpbs connection, when the LED is Off then 10Mpbs or no connection is available. LED D160 (Left LED) shows ACTIVITY presence.

Gigabit Ethernet Connector- CN23

Pin | Signal | Pin | Signal
1 | GBE_MDI0+ | 5 | GBE_MDI2-
2 | GBE_MDI0- | 6 | GBE_MDI1-
3 | GBE_MDI1+ | 7 | GBE_MDI3+
4 | GBE_MDI2+ | 8 | GBE_MDI3-

UDOO BOLT User Manual - Rev. First Edition: 1.0 - Last Edition: 1.0 - Author: S.B. - Reviewed by L.V. Copyright © 2019 SECO S.p.A. | 28
3.3.2 | USB ports
The AMD Ryzen Embedded V1000 family of Processors used on UDOO BOLT board can manage up to five USB SuperSpeed (i.e., USB 3.1 compliant) ports and six High Speed (i.e. USB 2.0 compliant) ports. There is only one dedicated High Speed port, the other five ports are shared with the SuperSpeed ports, i.e. they can be used either by USB 2.0 or USB 3.0.
The USB 3.1 ports #1 and #2 are available on two single USB connectors, CN21 and CN22, placed on the same side of the PCB (“Frontal”), while USB 3.1 ports #0 and #3 are available on USB connectors CN8 and CN9 placed on the opposite side (“Rear”). “Rear” and “Frontal” terms are used considering a possible application of this board with an enclosure). The connectors used are standard USB 3.0 type-A receptacles.
USB 3.1 ports’ connectors are standard type-A receptacle, they can be connected to all types of USB 1.1 / USB 2.0 / USB 3.0 devices using standard-A USB 3.x or USB 2.0 plugs.
For USB 3.x connections it is mandatory the use of SuperSpeed certified cables, whose SuperSpeed differential pairs are individually shielded inside the global cable’s external shielding.

Signal description:
USB_P1+/USB_P1-: USB 2.0 Port #1 differential pair.
USB_SSRX1+/USB_SSRX1-: USB Super Speed Port #1 receive differential pair. USB_SSTX1+/USB_SSTX1-: USB Super Speed Port #1 transmit differential pair. USB_P2+/USB_P2-: USB 2.0 Port #2 differential pair.
USB_SSRX1+/USB_SSRX1-: USB Super Speed Port #1 receive differential pair. USB_SSTX1+/USB_SSTX1-: USB Super Speed Port #1 transmit differential pair.
Common mode chokes are placed on all USB differential pairs for EMI compliance.
For ESD protection, on all data and voltage lines are placed clamping diodes for voltage transient suppression.

USB 3.1 port#1 type A receptacle CN21

Pin | Signal | Pin | Signal
1 | +5VUSB1 | 5 | USB_SSRX1-
2 | USB_P1- | 6 | USB_SSRX1+
3 | USB_P1+ | 7 | GND
4 | GND | 8 | USB_SSTX1-
| | 9 | USB_SSTX1+

USB 3.1 port #2 type-A receptacle CN22

Pin | Signal | Pin | Signal
1 | +5VUSB2 | 5 | USB_SSRX2-
2 | USB_P2- | 6 | USB_SSRX2+
3 | USB_P2+ | 7 | GND
4 | GND | 8 | USB_SSTX2-
| | 9 | USB_SSTX2+

UDOO BOLT User Manual - Rev. First Edition: 1.0 - Last Edition: 1.0 - Author: S.B. - Reviewed by L.V. Copyright © 2019 SECO S.p.A. | 29

USB ports #0 and #3, instead, are available on standard Type-C connectors (CN8 and CN9), with DisplayPort Alternate Mode and USB Dual Role Power Delivery (rel. 3.0) additional functionalities. This means that USB type-C connectors can be used to connect
external USB devices, DP/HDMI displays or used to supply the board by using a 60W minimum USB-C Power Adapter (power profile
20V 3A).
USB 3.1 Port #0 is internally multiplexed by the AMD Ryzen Embedded V100 Processor with Display Port #3, USB 3.1 Port #3 is multiplexed with Display Port #2.

Signal description:
USB0_A+/USB0_A-: USB 2.0 Port #0 differential pair, position 1.
USB0_B+/USB0_B-: USB 2.0 Port #0 differential pair, position 2.
USBC0_SSRXA+/USBC0_SSRXA-: USB Super Speed Port #0 receive first differential pair. When used for DP Alternate mode, this pair carries out Display Port #3 Differential pair #3.
USBC0_SSTXA+/USBC0_SSTXA-: USB Super Speed Port #1 transmit first differential pair. When used for DP Alternate mode, this pair carries out Display Port #3 Differential pair #2.

USB 3.1 port#0 type C receptacle CN8

Pin | Signal | Pin | Signal
A1 | GND | B12 | GND
A2 | USBC0_SSTXA+ | B11 | USBC0_SSRXA+
A3 | USBC0_SSTXA | B10 | USBC0_SSRXA-
A4 | VBUS_C0 | B9 | VBUS_C0
A5 | USBC0_CC1 | B8 | USBC0_SBU2
A6 | USB0_A+ | B7 | USB0_B-
A7 | USB0_A- | B6 | USB0_B+
A8 | USBC0_SBU1 | B5 | USBC0_CC2
A9 | VBUS_C0 | B4 | VBUS_C0
A10 | USBC0_SSRXB- | B3 | USBC0_SSTXB-
A11 | USBC0_SSRXB+ | B2 | USBC0_SSTXB+
A12 | GND | B1 | GND

USB 3.1 port #3 type-C receptacle CN9

Pin | Signal | Pin | Signal
A1 | GND | B12 | GND
A2 | USBC3_SSTXA+ | B11 | USBC3_SSRXA+
A3 | USBC3_SSTXA- | B10 | USBC3_SSRXA-
A4 | VBUS_C3 | B9 | VBUS _C3
A5 | USBC3_CC1 | B8 | USBC3_SBU2
A6 | USB3_A+ | B7 | USB3_B-
A7 | USB3_A- | B6 | USB3_B+
A8 | USBC3_SBU1 | B5 | USBC3_CC2
A9 | VBUS_C3 | B4 | VBUS_C3
A10 | USBC3_SSRXB- | B3 | USBC3_SSTXB-
A11 | USBC3_SSRXB+ | B2 | USBC3_SSTXB+
A12 | GND | B1 | GND

UDOO BOLT User Manual - Rev. First Edition: 1.0 - Last Edition: 1.0 - Author: S.B. - Reviewed by L.V. Copyright © 2019 SECO S.p.A. | 30

USBC0_SSRXB+/USBC0_SSRXB-: USB Super Speed Port #0 receive second differential pair. When used for DP Alternate mode, this pair carries out Display Port #3 Differential pair #0.
USBC0_SSTXB+/USBC0_SSTXB-: USB Super Speed Port #1 transmit second differential pair. When used for DP Alternate mode, this pair carries out Display Port #3 Differential pair #1.
USBC0_CC1: USB-C Port #0 Configuration Channel #1
USBC0_CC2: USB-C Port #0 Configuration Channel #2
USBC0_SBU1: USB-C Port #0 Sideband Use signal #1 When used for DP Alternate mode, this pair carries out Display Port #3 Aux Signal positive line. USBC0_SBU2: USB-C Port #0 Sideband Use signal #2. When used for DP Alternate mode, this pair carries out Display Port #3 Aux Signal negative line
VBUS_C0: USB-C Port #0 VBUS power rail. Can be used both for powering client devices with a 5V voltage (power source mode) or to power the whole board using an USB-C power adapter (power sink mode).
USB3_A+/USB3_A-: USB 2.0 Port #3 differential pair, position 1.
USB3_B+/USB3_B-: USB 2.0 Port #3 differential pair, position 2.
USBC3_SSRXA+/USBC3_SSRXA-: USB Super Speed Port #3 receive first differential pair. When used for DP Alternate mode, this pair carries out Display Port #2 Differential pair #3.
USBC3_SSTXA+/USBC3_SSTXA-: USB Super Speed Port #3 transmit first differential pair. When used for DP Alternate mode, this pair carries out Display Port #2 Differential pair #2.
USBC3_SSRXB+/USBC3_SSRXB-: USB Super Speed Port #3 receive second differential pair. When used for DP Alternate mode, this pair carries out Display Port #2 Differential pair #0.
USBC3_SSTXB+/USBC3_SSTXB-: USB Super Speed Port #3 transmit second differential pair. When used for DP Alternate mode, this pair carries out Display Port #2 Differential pair #1.
USBC3_CC1: USB-C Port #3 Configuration Channel #1
USBC3_CC2: USB-C Port #3 Configuration Channel #2
USBC3_SBU1: USB-C Port #3 Sideband Use signal #1 When used for DP Alternate mode, this pair carries out Display Port #2 Aux Signal positive line. USBC3_SBU2: USB-C Port #3 Sideband Use signal #2. When used for DP Alternate mode, this pair carries out Display Port #2 Aux Signal negative line
VBUS_C3: USB-C Port #3 VBUS power rail. Can be used both for powering client devices with a 5V voltage (power source mode) or to power the whole board using an USB-C power adapter (power sink mode).

UDOO BOLT User Manual - Rev. First Edition: 1.0 - Last Edition: 1.0 - Author: S.B. - Reviewed by L.V. Copyright © 2019 SECO S.p.A. | 31
3.3.3 | HDMI connectors
The AMD Ryzen Embedded V1000 family of Processors offer four Digital Display Interfaces, configurable to work in HDMI/DVI/DP++ modes.
On the UDOO BOLT board, the Digital Display Interfaces #0 and #1 are used to implement two HDMI 2.0 interfaces through as many HDMI 2.0 ReDriver / Level shifters and ESD protection + signal conditioning ICs.
Therefore, on-board there are two standard certified HDMI connector, right-angle, type A, MOLEX P/N 47151-1001.

Signals involved in HDMI management are the following: HDMI0_CLK+/ HDMI0_CLK-: HDMI port #0 differential Clock. HDMI0_LANE0+/ HDMI0_LANE0-: HDMI port #0 differential pair #0 HDMI0_LANE1+/ HDMI0_LANE1-: HDMI port #0 differential pair #1
HDMI0_LANE2+/HDMI0_LANE2-: HDMI port #0 differential pair #2

HDMI0_SDA: DDC Data line for HDMI port #0. Bidirectional signal, electrical level +5VHDMI0 with a 1k87Ω pull-up resistor.

HDMI0_SCL: DDC Clock line for HDMI port #0. Output signal, electrical level +5VHDMI0 with a 1k87Ω pull-up resistor.

HDMI Connector #1 CN19

Pin | Signal | Pin | Signal
1 | HDMI1_LANE2+ | 2 | GND
3 | HDMI1_LANE2- | 4 | HDMI1_LANE1+
5 | GND | 6 | HDMI1_LANE1-
7 | HDMI1_LANE0+ | 8 | GND
9 | HDMI1_LANE0- | 10 | HDMI1_CLK+
11 | GND | 12 | HDMI1_CLK-
13 | HDMI1_CEC | 14 | HDMI1_UTILITY
15 | HDMI1_SCL | 16 | HDMI1_SDA
17 | GND | 18 | +5VHDMI1
19 | HDMI1_HPD

HDMI Connector #0 CN20

Pin | Signal | Pin | Signal
1 | HDMI0_LANE2+ | 2 | GND
3 | HDMI0_LANE2- | 4 | HDMI0_LANE1+
5 | GND | 6 | HDMI0_LANE1-
7 | HDMI0_LANE0+ | 8 | GND
9 | HDMI0_LANE0- | 10 | HDMI0_CLK+
11 | GND | 12 | HDMI0_CLK-
13 | HDMI0_CEC | 14 | HDMI0_UTILITY
15 | HDMI0_SCL | 16 | HDMI0_SDA
17 | GND | 18 | +5VHDMI0
19 | HDMI0_HPD

UDOO BOLT User Manual - Rev. First Edition: 1.0 - Last Edition: 1.0 - Author: S.B. - Reviewed by L.V. Copyright © 2019 SECO S.p.A. | 32

HDMI0_CEC: HDMI Consumer Electronics Control (CEC) Line. Bidirectional signal, electrical level +3.3V_DSW with a 27kΩ pull-up resistor and Schottky Diode. HDMI0_HPD: HDMI Port #0 Hot Plug Detect Input signal. +5VHDMI0 electrical level signal with dynamic pull-down.
HDMI0_UTILITY: HDMI Port #0 Utility Input signal. +5VHDMI0 electrical level signal.

HDMI1_CLK+/ HDMI1_CLK-: HDMI port #1 differential Clock.
HDMI1_LANE0+/ HDMI1_LANE0-: HDMI port #1differential pair #0 HDMI1_LANE1+/ HDMI1_LANE1-: HDMI port #1differential pair #1
HDMI1_LANE2+/HDMI1_LANE2-: HDMI port #1differential pair #2

HDMI1_SDA: DDC Data line for HDMI port #1. Bidirectional signal, electrical level +5VHDMI1 with a 1k87Ω pull-up resistor.

HDMI1_SCL: DDC Clock line for HDMI port #1. Output signal, electrical level +5VHDMI1 with a 1k87Ω pull-up resistor.

HDMI1_CEC: HDMI Consumer Electronics Control (CEC) Line. Bidirectional signal, electrical level +3.3V_DSW with a 27kΩ pull-up resistor and Schottky Diode. HDMI1_HPD: HDMI Port #1 Hot Plug Detect Input signal. +5VHDMI1 electrical level signal with dynamic pull-down.
HDMI1_UTILITY: HDMI Port #1 Utility Input signal. +5VHDMI1 electrical level signal.

All data and voltage lines are protected against ESD.
Always use HDMI-certified cables for the connection between the board and the HDMI display; a category 2 (High-Speed) cable is recommended for higher resolutions, category 1 cables can be used for 720p resolution.

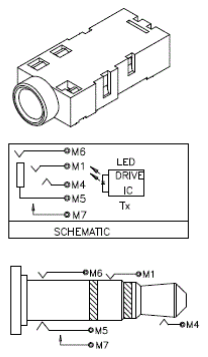
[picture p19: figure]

UDOO BOLT User Manual - Rev. First Edition: 1.0 - Last Edition: 1.0 - Author: S.B. - Reviewed by L.V. Copyright © 2019 SECO S.p.A. | 33
3.3.4 | Audio interfaces

In the UDOO BOLT board, audio functionalities are provided by a Realtek ALC888S High Definition Audio Codec.

In order to reduce the space dedicated to connectors, there is a TRRS Combo Audio Socket, i.e. a single socket which offer both stereo Line Out and Mic In functionalities.
Such TRRS Combo Audio socket can be used with any 4-poles 3.5mm diameter audio jack, with pinout compatible with the most recent Headsets, shown in the table on the left.

Additionally, it is also possible to connect external stereo speakers by using the dedicated connectors CN29 and CN30, which are two connectors type HR p/n A2001WV-S-02PD01 or equivalent.
Mating connector: HR p/n A2001H-02P with A2001 series female crimp terminals.
The speaker output available on connectors CN29 and CN30 is Class-D amplified, 3W global power on 4Ohm Load / 1.7W global power on 8Ohm load (recommended).

Furthermore, on the Rear panel Side, there is a combo analogic / digital connector, a TRS 3.5mm audio socket which integrates also a LED Transmitter for S/PDIF optical connections (Optical 3.5mm jack). This connector can therefore be used to connect both analog headsets (TRS plug) and digital audio devices (coaxial optical cable with 3.5mm jack, like in the picture).

TRRS Audio headset jack- CN11

Pin | Signal
TIP | Headphone Out Left Channel
RING1 | Headphone Out Right Channel
RING2 | MIC-/MIC+
SLEEVE | MIC+/MIC-

Right Speaker Connector- CN29

Pin | Signal
1 | Speaker Right Channel +
2 | Speaker Right Channel -

Left Speaker Connector- CN30

1 | Speaker Left Channel -
2 | Speaker Left Channel +

TRS Headphone + S/PDIF -
CN12
Pin | Signal
TIP | Headphone Out Left Channel
RING | Headphone Out Right Channel
SLEEVE | GND

UDOO BOLT User Manual - Rev. First Edition: 1.0 - Last Edition: 1.0 - Author: S.B. - Reviewed by L.V. Copyright © 2019 SECO S.p.A. | 34
3.3.5 | Buttons / LED header

To allow the integration of a UDOO BOLT based system inside a box PC-like, there is a connector on the board that allows to remote signals for the Power Button (to be used to put the system in a Soft Off State, or awake from it), for the Reset Button, and the signal for optional LED signalling activity on SATA Channel and Power On states.
The pinout of this connector complies with Intel® Front Panel I/O connectivity
Design Guide, Switch/LED Front Panel section, chapter 2.2. It is shown in the
table on the left.
Connector CN6 is an internal 9-pin standard male pin header, p 2.54 mm, 5+4 pin, h= 6mm, type NELTRON p/n 2213S-10G-E10 or equivalent.

Signals Description
HD_LED_P: Hard Disk Activity LED signal’s pull-up to +5V_RUN voltage (510Ω pull-up). HD_LED_N: Hard Disk Activity LED output signal
RST_SW_N: Reset Button GND
RST_SW_P: Reset button input signal. This signal has to be connected to an external momentary pushbutton (contacts normally open). When the pushbutton is pressed, the pulse of Reset signal will cause the reset of the board. +3.3V_DSW electrical level with 4k7Ω pull-up.

PWR_SW_P: Power button input signal, +3.3V_DSW electrical level with 4k7Ω pull-up. This signal can be connected to an external momentary pushbutton (contacts normally open). Upon the pressure of this pushbutton, the pulse of this signal will let the switched voltage rails turn on or off. Please be aware that this signal is also driven by the momentary pushbutton located on-board, near the header itself (please refer to the picture at page 25).
PWR_SW_N: Power button GND
FP PWR_P/SLP_N: Power/Sleep messaging LED terminal 1 with 510Ω pull-up resistor to +5V_ALW voltage. Connect it to an extremity of a dual-color power LED for power ON/OFF, sleep and message waiting signalling. Please refer to Intel

® Front Panel I/O connectivity Design Guide, chapter 2.2.4, for LED functionalities and signal meaning.
FP PWR_N/SLP_P: Power/Sleep messaging LED terminal 2 with 510Ω pull-up resistor to +5V_ALW voltage. Connect it to the other extremity of the dual-color power LED above mentioned.

Buttons / LED Header CN6

Pin | Signal | Pin | Signal
1 | HD_LED_P | 2 | FP PWR_P/SLP_N
3 | HD_LED_N | 4 | FP PWR_N/SLP_P
5 | RST_SW_N | 6 | PWR_SW_P
7 | RST_SW_P | 8 | PWR_SW_N
9 | ---

UDOO BOLT User Manual - Rev. First Edition: 1.0 - Last Edition: 1.0 - Author: S.B. - Reviewed by L.V. Copyright © 2019 SECO S.p.A. | 35

3.3.6 SATA connectors

The AMD Ryzen Embedded V1000 family of Processors embed a SATA Controller, which offers two SATA III, 6.0 Gbps interfaces.
Of these interfaces, one SATA channel is carried out to a standard male S-ATA connector, CN14 (the
other SATA channel is available on the M.2 Key B socket, CN18, please check par. 3.3.7).
Here following the signals related to SATA interface:
SATA1_TX+/SATA1_TX-: Serial ATA Channel #1 Transmit differential pair
SATA1_RX+/SATA1_RX-: Serial ATA Channel #1 Receive differential pair
10nF AC series decoupling capacitors are placed on each line of SATA differential pairs.

A dedicated power connector, CN15, can be used to give supply to external Hard Drives (or Solid State Drives) connected to the SATA male connector.
The dedicated power connector is a 4-pin male connector, type JST p/n S4B-PH-SM4-TB or equivalent, with pinout shown in the table on the left.
Mating connector: JST PHR-4 crimp housing with JST SPH-002T-P0.5L crimp terminals.
Maximum allowed power consumption for this connector is 1A.

SATA Connector - CN14

Pin | Signal
1 | GND
2 | SATA1_Tx+
3 | SATA1_Tx-
4 | GND
5 | SATA1_Rx-
6 | SATA1_Rx+
7 | GND

S-ATA Power Connector CN15

Pin | Signal
1 | ---
2 | GND
3 | GND
4 | +5V_RUN

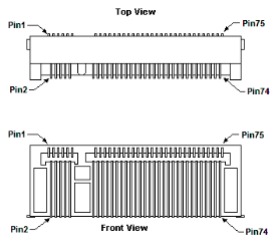
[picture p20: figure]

UDOO BOLT User Manual - Rev. First Edition: 1.0 - Last Edition: 1.0 - Author: S.B. - Reviewed by L.V. Copyright © 2019 SECO S.p.A. | 36
3.3.7 | M.2 SATA/PCI-e Slot: Socket 2 Key B type 2242/2260 The mass storage capabilities of the UDOO BOLT are completed by an M.2 SSD Slot, which allow plugging M.2 Socket 2 Key B Solid State Drives with SATA interface or PCI- e x2 interface (PCI-e x1 is also supported).
| The connector used for the M.2 SATA/PCI-e slot is CN18, which is a standard 75 pin M.2 Key B connector, type LOTES p/n APCI0087-P001A, H=8.5mm, with the pinout shown in the table on the left. On the UDOO BOLT board there is also a Threaded Spacer which allows the placement of M.2 Socket 2 Key B SATA/PCI- e modules in 2260 size. It is possible to place also modules in 2242 or 2260 size, by using a M/F Spacer which allows fixing the M.2 module on the spacer already available on the PCB, deemed for the fixing of the M.2 connectivity slot (see next paragraph)
| Here following the signals related to the SATA interface: SATA0_Tx+/SATA0_Tx-: Serial ATA Channel #0 Transmit differential pair SATA0_Rx+/SATA0_Rx-: Serial ATA Channel #0 Receive differential pair 10nF AC series decoupling capacitors are placed on each line of SATA differential pairs. Here following the signals related to the PCI-e interface: PCIe0_TX+/PCIe0_TX-: PCI Express lane #0, Transmitting Output Differential pair PCIe0_RX+/PCIe0_RX-: PCI Express lane #0, Receiving Input Differential pair PCIe1_TX+/PCIe1_TX-: PCI Express lane #1, Transmitting Output Differential pair PCIe1_RX+/PCIe1_RX-: PCI Express lane #1, Receiving Input Differential pair PCIe0_Clock+ / PCIe0_Clock-: PCI Express Reference Clock for lane #2, Differential Pair PLT_RST#: Reset Signal that is sent from the SoC to all PCI-e devices available on the board (i.e. the GbE controller, the PCI-e based SSD modules plugged in the CN18 slot, the PCI-e x4 NVMe modules plugged in CN17slot and the connectivity modules plugged in CN16 slot). It is a 3.3V_RUN active-low signal.

M.2 SATA/PCI-e Slot CN18

Pin | Signal | Pin | Signal
1 | --- | 2 | +3.3V_RUN
3 | GND | 4 | +3.3V_RUN
5 | GND | 6 | ---
7 | --- | 8 | ---
9 | --- | 10 | ---
11 | GND
| | 20 | ---
21 | --- | 22 | ---
23 | --- | 24 | ---
25 | --- | 26 | ---
27 | GND | 28 | ---
29 | PCIe1_Rx- | 30 | ---
31 | PCIe1_Rx+ | 32 | ---
33 | GND | 34 | ---
35 | PCIe1_Tx- | 36 | ---
37 | PCIe1_Tx+ | 38 | ---
39 | GND | 40 | ---
41 | SATA0_Rx+/PCIe0_Rx- | 42 | ---
43 | SATA0_Rx-/PCIe0_Rx+ | 44 | ---
45 | GND | 46 | ---
47 | SATA0_Tx-/PCIe0_Tx- | 48 | ---
49 | SATA0_Tx+/PCIe0_Tx+ | 50 | PLT_RST#
51 | GND | 52 | PCIE_REQ0#
53 | PCIe0_Clock- | 54 | ---
55 | PCIe0_Clock+ | 56 | ---
57 | GND | 58 | ---

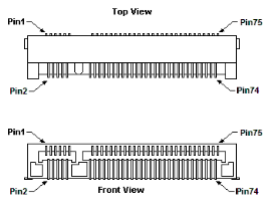
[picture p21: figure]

UDOO BOLT User Manual - Rev. First Edition: 1.0 - Last Edition: 1.0 - Author: S.B. - Reviewed by L.V. Copyright © 2019 SECO S.p.A. | 37

PCIe_REQ0#: PCI Express Clock Request Input, active low signal. This signal shall be driven low by any module inserted in the connectivity slot, in order to ensure that the SoC makes available the reference clock.
CONFIG_1: Configuration input signal, +3.3V_RUN signal with 10kΩ pull-up. This signal is necessary to switch between the S-ATA and the PCI-e signals on the pins 41/43/47/49 of connector CN18. When CONFIG_1 signal is high, then PCI-e x 2 interface is available on connector CN18. When the signal is driven low, then SATA interface will be available. The selection is automatic, since according to M.2 specifications for Socket2 SSD modules, CONFIG_1 signal must be low for SSD based modules and high for PCI-e based modules. The PCI-e x2 interface can be used also for different purposes other than SSD modules, but it is important that the CONFIG_1 signal is driven properly (it can be left unconnected on PCI-e based modules, due to the presence of the pull-up resistor on the platform). 3.3.8 M.2 Connectivity Slot: Socket 1 Key E Type 2230
It is possible to increase the connectivity of the UDOO BOLT
board by using M.2 Socket 1 Key E connectivity modules (i.e. modules with functionalities like WiFi + Bluetooth).
The connector used for the M.2 Connectivity slot is CN16, which is a standard 75 pin M.2 Key E connector, type LOTES
p/n APCI0076-P001A, H=4.2mm, with the pinout shown in
the table on the left.
On the UDOO BOLT board there is also a Threaded Spacer which allows the placement of M.2 Socket 1 Key E connectivity modules in 2230 size.
Here following the signals related to this connectivity interface:
USB_P4+/USB_P4-: USB 2.0 Port #4 differential pair.
PCIe4_TX+/PCIe4_TX-: PCI Express lane #4, Transmitting Output Differential pair PCIe4_RX+/PCIe4_RX-: PCI Express lane #4, Receiving Input Differential pair
PCIe4_Clock+ / PCIe4_Clock-: PCI Express Reference Clock for lane #4, Differential Pair M.2_WAKE#: Board’s Wake Input, 3.3V_A active low signal. It must be externally driven by the Connectivity module plugged in the slot when it requires waking up the system.
PLT_RST#: Reset Signal that is sent from the SoC to all PCI-e devices available on the board
59 | --- | 60 | ---
61 | --- | 62 | ---
63 | --- | 64 | ---
65 | --- | 66 | ---
67 | --- | 68 | ---
69 | CONFIG_1 | 70 | +3.3V_RUN
71 | GND | 72 | +3.3V_RUN
73 | GND | 74 | +3.3V_RUN
75 | ---

M.2 Connectivity Slot - CN16

Pin | Signal | Pin | Signal
1 | GND | 2 | +3.3V_ALW
3 | USB_P4+ | 4 | +3.3V_ALW
5 | USB_P4- | 6 | ---
7 | GND | 8 | ---
9 | --- | 10 | ---
11 | --- | 12 | ---
13 | --- | 14 | ---
15 | --- | 16 | ---
17 | --- | 18 | GND
19 | --- | 20 | ---
21 | --- | 22 | ---
23 | ---
| | 32 | ---
33 | GND | 34 | ---
35 | PCIe4_Tx+ | 36 | ---

UDOO BOLT User Manual - Rev. First Edition: 1.0 - Last Edition: 1.0 - Author: S.B. - Reviewed by L.V. Copyright © 2019 SECO S.p.A. | 38

(i.e. the GbE controller, the PCI-e based SSD modules plugged in the CN16 slot, the connectivity modules plugged in CN18 slot, the PCI-e x4 NVMe modules plugged in CN17slot). It is a 3.3V_RUN active-low signal.
PCIe_REQ4#: PCI Express Clock Request Input, active low signal. This signal shall be driven low by any module inserted in the connectivity slot, in order to ensure that the SoC makes available the reference clock.
SUS_CLK: 32.768kHz Clock provided by the UDOO BOLT board to the module plugged in the slot CN16. +3.3V_ALW electrical level.
BT_DISABLE#: Bluetooth module disable, active low signal, +3.3V_ALW electrical level. This signal can be used to disable Bluetooth functionalities of any connectivity module plugged in CN16 Slot.
WIFI_DISABLE#; WiFi module disable, active low signal, +3.3V_ALW electrical level. This signal can be used to disable WiFi functionalities of any connectivity module plugged in CN16 Slot.
37 | PCIe4_Tx- | 38 | ---
39 | GND | 40 | ---
41 | PCIe4_Rx+ | 42 | ---
43 | PCIe4_Rx- | 44 | ---
45 | GND | 46 | ---
47 | PCIe4_CLK+ | 48 | ---
49 | PCIe4_CLK- | 50 | SUS_CLK
51 | GND | 52 | PLT_RST#
53 | PCIe_REQ4# | 54 | BT_DISABLE#
55 | M.2_WAKE# | 56 | WIFI_DISABLE
57 | GND | 58 | ---
59 | --- | 60 | ---
61 | --- | 62 | ---
63 | GND | 64 | ---
65 | --- | 66 | ---
67 | --- | 68 | ---
69 | GND | 70 | ---
71 | --- | 72 | +3.3V_ALW
73 | --- | 74 | +3.3V_ALW
75 | GND

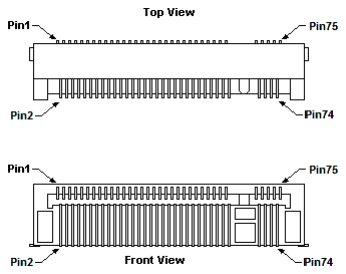
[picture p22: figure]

UDOO BOLT User Manual - Rev. First Edition: 1.0 - Last Edition: 1.0 - Author: S.B. - Reviewed by L.V. Copyright © 2019 SECO S.p.A. | 39

3.3.9 M.2 NVMe Slot: Socket 3 Key M Type 2280 Another possibility for connecting mass storage devices is given by the M.2 Key M Slot, which allows the plugging of M.2 High Capacity SSD drives with PCI-e x4 interface.
The connector used for the M.2 SSD slot is CN17, which is a standard 75 pin M.2 Key M connector, type LOTES p/n APCI0096-P005H, H=8.5mm, with the pinout shown in the
table on the left.
On the UDOO BOLT board there is also a Threaded Spacer
which allows the placement of M.2 Socket 3 Key M PCI-e SSD modules in 2280 size. Here following the signals related to this connectivity interface:
GFX_Tx0+/GFX_Tx0-: PCI-e GFX port x4 lane #0, Transmitting Output Differential pair GFX_Rx0+/GFX_Rx0-: PCI-e GFX port x4 lane #0, Receiving Input Differential pair GFX_Tx1+/GFX_Tx1-: PCI-e GFX port x4 lane #1, Transmitting Output Differential pair GFX_Rx1+/GFX_Rx1-: PCI-e GFX port x4 lane #1, Receiving Input Differential pair GFX_Tx2+/GFX_Tx2-: PCI-e GFX port x4 lane #2, Transmitting Output Differential pair GFX_Rx2+/GFX_Rx2-: PCI-e GFX port x4 lane #2, Receiving Input Differential pair GFX_Tx3+/GFX_Tx3-: PCI-e GFX port x4 lane #3, Transmitting Output Differential pair GFX_Rx3+/GFX_Rx3-: PCI-e GFX port x4 lane #3, Receiving Input Differential pair PCIe4_Clock+ / PCIe4_Clock-: PCI Express Reference Clock for lane #4, Differential Pair PLT_RST#: Reset Signal that is sent from the SoC to all PCI-e devices available on the board (i.e. the GbE controller, the PCI-e based SSD modules plugged in the CN16 slot, the connectivity modules plugged in CN18 slot, the PCI-e x4 NVMe modules plugged in CN17slot). It is a 3.3V_RUN active-low signal.
GFX_REQ#: PCI Express GFX Clock Request Input, active low signal. This signal shall be driven low by any module inserted in the connectivity slot, in order to ensure that the SoC makes available the reference clock.

M.2 NVMe Slot - CN17

Pin | Signal | Pin | Signal
1 | GND | 2 | +3.3V_RUN
3 | GND | 4 | +3.3V_RUN
5 | GFX_Rx3- | 6 | ---
7 | GFX_Rx3+ | 8 | ---
9 | GND | 10 | ---
11 | GFX_Tx3- | 12 | +3.3V_RUN
13 | GFX_Tx3+ | 14 | +3.3V_RUN
15 | GND | 16 | +3.3V_RUN
17 | GFX_Rx2- | 18 | +3.3V_RUN
19 | GFX_Rx2+ | 20 | ---
21 | GND | 22 | ---
23 | GFX_Tx2- | 24 | ---
25 | GFX_Tx2+ | 26 | ---
27 | GND | 28 | ---
29 | GFX_Rx1- | 30 | ---
31 | GFX_Rx1+ | 32 | ---
33 | GND | 34 | ---
35 | GFX_Tx1- | 36 | ---
37 | GFX_Tx1+ | 38 | ---
39 | GND | 40 | ---
41 | GFX_Rx0- | 42 | ---
43 | GFX_Rx0+ | 44 | ---
45 | GND | 46 | ---
47 | GFX_Tx0- | 48 | ---
49 | GFX_Tx0+ | 50 | PLT_RST#
51 | GND | 52 | GFX_REQ#

UDOO BOLT User Manual - Rev. First Edition: 1.0 - Last Edition: 1.0 - Author: S.B. - Reviewed by L.V. Copyright © 2019 SECO S.p.A. | 40

3.3.10 FAN connector

Depending on the usage model of UDOO BOLT, for critical applications/environments on UDOO BOLT it is available a 3-pin single line SMT connector for an external +5VDC FAN.
The Connector is a type MOLEX 53398-0571 or equivalent, with pinout shown in the table on the left.
Mating connector: MOLEX 51021-0300 receptacle with MOLEX 50079-8000 female crimp terminals.
Please be aware that the use of an external fan depends strongly on customer’s application/installation. FAN_POWER: +5V_ALW derived power rail for FAN.
FAN_TACHO_IN: tachometric input from the FAN to the embedded microcontroller, +3.3V_RUN electrical level signal with 10kΩ pull-up resistor.
53 | PEG_CLK- | 54 | ---
55 | PEG_CLK+ | 56 | ---
57 | GND | 58 | ---
67 | --- | 68 | ---
69 | --- | 70 | +3.3V_RUN
71 | GND | 72 | +3.3V_RUN
73 | GND | 74 | +3.3V_RUN
75 | GND

FAN Connector CN7

Pin | Signal
1 | GND
2 | FAN_POWER
3 | FAN_TACHO_IN

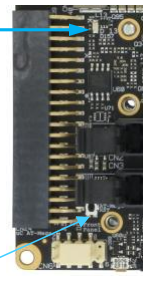
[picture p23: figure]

UDOO BOLT User Manual - Rev. First Edition: 1.0 - Last Edition: 1.0 - Author: S.B. - Reviewed by L.V. Copyright © 2019 SECO S.p.A. | 41

3.3.11 ARDUINO interface

On a dual row p.2.54mm dedicated female header is realised an Arduino Leonardo interface, which is managed by an ATMEL ATmega32U4 microcontroller, connected to the AMD Ryzen Embedded V1000 processor via an internal USB. It’s exactly the same thing as having an Arduino Leonardo board attached via USB to a standard PC.
It is possible to refer to Arduino Leonardo documentation for a description of the signals available on this connector, and the way to use them.

Near the connector, there is also an integrated Yellow SMT LED, which indicates the proper working of Arduino section. This LED is driven by using IO13* signal, it’s working depends on the programming of ATmega32u4 microcontroller.

On- | buttons/led header CN6,
it is also available a miniaturized momentary switch, that can be used to reset the ATmega32u4 microcontroller.

Arduino Interface Connector CN24

Pin | Signal | Pin | Signal
1 | A5 | 2 | D0 / RX
3 | A4 | 4 | D1 / TX
5 | A3 | 6 | D2 / SDA
7 | A2 | 8 | D3 / SCL
9 | A1 | 10 | D4
11 | A0 | 12 | D5*
13 | --- | 14 | D6*
15 | GND | 16 | D7
17 | GND | 18 | IO8
19 | 5V_OUT | 20 | IO9*
21 | 3.3V_OUT | 22 | IO10*
23 | RESET# | 24 | IO11*
25 | 5V_OUT | 26 | IO12
27 | MISO | 28 | IO13*
29 | MOSI | 30 | GND
31 | SCK | 32 | AREF
33 | GND | 34 | D2/SDA
35 | RXLED | 36 | D3/SCL
37 | TXLED | 38 | GND
39 | 5V_OUT | 40 | 5V_OUT

Arduino LED

ATMega32u4
Reset Button

UDOO BOLT User Manual - Rev. First Edition: 1.0 - Last Edition: 1.0 - Author: S.B. - Reviewed by L.V. Copyright © 2019 SECO S.p.A. | 42

3.3.12 GROVE connectors

The UDOO Bolt board offers the possibility of managing Seeed Technology Grove family of sensors through the Arduino platform by using three dedicated connectors, directly managed by the ATmega ATmega32u4 controller.

All three connectors are type TKP p/n P20Y1L-04SMT or equivalent, with the pinout shown in the tables on the left.
Mating connector: TKP receptacle p/n H20Y1-04 with TKP DHT-1S(LF) female crimp terminals. The signals available on these three connectors are the same available on the Arduino interface connector CN24.

Please notice that these connectors seems to be mirrored with respect to GROVE standard connectors. Actually, the pinout shown in these tables is referred to the real pin position #1 engraved on the connector. Cables designed for GROVE sensors will fit into these connectors without needing any change.

GROVE Analog connector CN26

Pin | Signal | GROVE standard ref.
1 | GND | 4
2 | 5V_OUT | 3
3 | A1 | 2
4 | A0 | 1

GROVE Digital / UART connector - CN27

Pin | Signal | GROVE standard ref.
1 | GND | 4
2 | 5V_OUT | 3
3 | D1/TX | 2
4 | D0/RX | 1

GROVE Digital / I2C connector CN28

Pin | Signal | GROVE standard ref.
1 | GND | 4
2 | 5V_OUT | 3
3 | D2 / SDA | 2
4 | D3 / SCL | 1

UDOO BOLT User Manual - Rev. First Edition: 1.0 - Last Edition: 1.0 - Author: S.B. - Reviewed by L.V. Copyright © 2019 SECO S.p.A. | 43

3.3.13 Embedded Controller I/O Header
On board’s bottom sidem there is another dual row 40-pin p 2.54mm female header, which makes available other signals for possible external expansions, that are directly managed by the Embedded Controller.
More specifically, on this connector will be available an SPI interface, a FAN Control interface, two I2C interfaces, a Matrix scan interface and two UARTs, where some interfaces share the same pins. Most of these signals can also be used as GPIOs.
Please notice that JTAG interface and Private Flash Interface, described below, are disabled to the end-users, since they are reserved for manufacturing purposes.
Here following the description of the signals available on this connector:
EC_SPI_MOSI: EC’s SPI #0 interface Master Out Slave In output Signal, electrical level +3.3V_DSW.
EC_SPI_MISO: EC’s SPI #0 interface Master In Slave Out input Signal, electrical level +3.3V_DSW
EC_SPI_CS#: EC’s SPI #0 interface Chip Select active low output signal, electrical level +3.3V_DSW
EC_SPI_CLK: EC’s SPI #0 interface Clock output, electrical level +3.3V_DSW
EC_NRST: EC’s JTAG interface Reset input signal, electrical level +3.3V_DSW with 10kΩ pull-down resistor
EC_TDO_I2C_SCL2: EC’s JTAG interface Test Data Out output signal / I2C Port #9 Clock line. Output signal, electrical level +3.V_DSW with 2k2Ω pull-up resistor.
EC_TDI_I2C_SDA2: : EC’s JTAG interface Test Data IN input signal / I2C Port #9 data line. Bidirectional signal, electrical level +3.3V_DSW with 2k2Ω pull-up resistor.
EC_TMS_I2C_SCL1: EC’s JTAG interface Test Mode Select output signal / I2C Port #8 Clock line. Output signal, electrical level +3.V_DSW with 2k2Ω pull-up resistor
EC_TCK_I2C_SDA1: EC’s JTAG interface Test Clock signal / I2C Port #8 data line. Bidirectional signal, electrical level +3.3V_DSW with 2k2Ω pull-up resistor.

WAKE# EC Wake# capable Input Signal, electrical level +3.3V_DSW with 2k2Ω pull-up resistor FANOUT0: EC PWM #0 Output Signal, electrical level +3.3V_DSW.
FANTACH0: EC FAN Tachometric #0 Input signal, electrical level +3.3V_DSW.

Embedded controller Feature header CN25

Pin | Signal | Pin | Signal
1 | EC_SPI_MISO | 2 | EC_SPI_CS#
3 | EC_SPI_MOSI | 4 | EC_SPI_CLK
5 | EC_NRST | 6 | WAKE#
7 | EC_TDO_I2C_SCL2 | 8 | EC_TMS_I2C_SCL1
9 | EC_TDI_I2C_SDA2 | 10 | EC_TCK_I2C_SDA1
11 | FANOUT0 | 12 | FANTACH0
13 | EC_KSO0 | 14 | EC_KSI0
15 | EC_KSO1 | 16 | EC_KSI1
17 | EC_KSO2 | 18 | EC_KSI2
19 | EC_KSO3 | 20 | EC_KSI3
21 | EC_KSO4 | 22 | EC_KSI4
23 | EC_KSO8_PVTIO0 | 24 | EC_KSO11_PVTCS#
25 | EC_KSO9_PVTIO1 | 26 | EC_KSO12_PVTCLK
27 | EC_KSO10_PVTIO2 | 28 | EC_KSO13_PVTIO3
29 | GND | 30 | +3.3V_OUT
31 | GND | 32 | +3.3V_OUT
33 | EC_UART_RxD1 | 34 | EC_UART_RxD0
35 | EC_UART_TxD1 | 36 | EC_UART_TxD0
37 | EC_UART_RTS#1 | 38 | EC_UART_RTS#0
39 | EC_UART_CTS#1 | 40 | EC_UART_CTS#0

UDOO BOLT User Manual - Rev. First Edition: 1.0 - Last Edition: 1.0 - Author: S.B. - Reviewed by L.V. Copyright © 2019 SECO S.p.A. | 44

EC_KSO0: EC Keyboard Matrix Scan Output #0, electrical level +3.3V_DSW EC_KSO1: EC Keyboard Matrix Scan Output #1,electrical level +3.3V_DSW EC_KSO2: EC Keyboard Matrix Scan Output #2,electrical level +3.3V_DSW EC_KSO3: EC Keyboard Matrix Scan Output #3, electrical level +3.3V_DSW EC_KSO4: EC Keyboard Matrix Scan Output #4,electrical level +3.3V_DSW EC_KSI0: EC Matric Scan Input #0,electrical level +3.3V_DSW
EC_KSI1: EC Keyboard Matrix Scan Input #1,electrical level +3.3V_DSW EC_KSI2: EC Keyboard Matrix Scan Input #2, electrical level +3.3V_DSW EC_KSI3: EC Keyboard Matrix Scan Input #3, electrical level +3.3V_DSW
EC_KSI4: EC Keyboard Matrix Scan Input #4, electrical level +3.3V_DSW
EC_KSO8_PVTIO0: EC Keyboard Matrix Scan Output #8 / Private Flash port Data 0, bidirectional signal electrical level +3.3V_DSW EC_KSO9_PVTIO1: EC Keyboard Matrix Scan Output #9 / Private Flash port Data 1, bidirectional signal electrical level +3.3V_DSW EC_KSO10_PVTIO2: EC Keyboard Matrix Scan Output #10 / Private Flash port Data 2, bidirectional signal, electrical level +3.3V_DSW EC_KSO11_PVTCS#: EC Keyboard Matrix Scan Output #11 / Private Flash port Chip Select, output signal, electrical level +3.3V_DSW EC_KSO12_PVTCLK: EC Keyboard Matrix Scan Output #12 / Private Flash port Clock, output signal electrical level +3.3V_DSW EC_KSO13_PVTIO3: EC Keyboard Matrix Scan Output #13 / Private Flash port Data 3, bidirectional signal electrical level +3.3V_DSW EC_UART_RxD0: EC UART #0, Serial data Receive (input) line, +3.3V_DSW electrical level.
EC_UART_TxD0: EC UART #0, Serial data Transmit (output) line, +3.3V_DSW electrical level.
EC_UART_CTS#0: EC UART #0, Handshake signal, Clear to Send (Input) line, +3.3V_DSW electrical level. EC_UART_RTS#0: EC UART #0, Handshake signal, Request to Send (output) line, +3.3V_DSW electrical level. EC_UART_RxD1: EC UART #1, Serial data Receive (input) line, +3.3V_DSW electrical level.
EC_UART_TxD1: EC UART #1, Serial data Transmit (output) line, +3.3V_DSW electrical level.
EC_UART_CTS#1: EC UART #1, Handshake signal, Clear to Send (Input) line, +3.3V_DSW electrical level. EC_UART_RTS#1: EC UART #1, Handshake signal, Request to Send (output) line, +3.3V_DSW electrical level.

UDOO BOLT User Manual - Rev. First Edition: 1.0 - Last Edition: 1.0 - Author: S.B. - Reviewed by L.V. Copyright © 2019 SECO S.p.A. | 45

3.3.14 IR Receiver
The UDOO BOLT board embeds an IR receiver, which allows using a remote control when the board is placed in an enclosure (like, i.e., on Set Top Boxes). The Infrared Receiver is SMD Type, p/n TSOP75238TR, and works with 38kHz carrier frequency.
The IR port is managed by the embedded microcontroller.
3.3.15 UEFI BIOS Default Restore switch
In some cases, a wrong configuration of BIOS parameters could lead the module in an unusable state (i.e. no video output, all USB HID devices disabled). For these cases, on the module it has been placed a 3-way switch which can be used to restore the BIOS to factory default configuration. To do so, it is necessary to place the contact of the switch in 1-2 position, then turn on the module, wait until the board resets itself then turn off the module. The contact MUST be now placed back to 2-3 position.
During normal use, the contact MUST be always placed in 2-3 position.

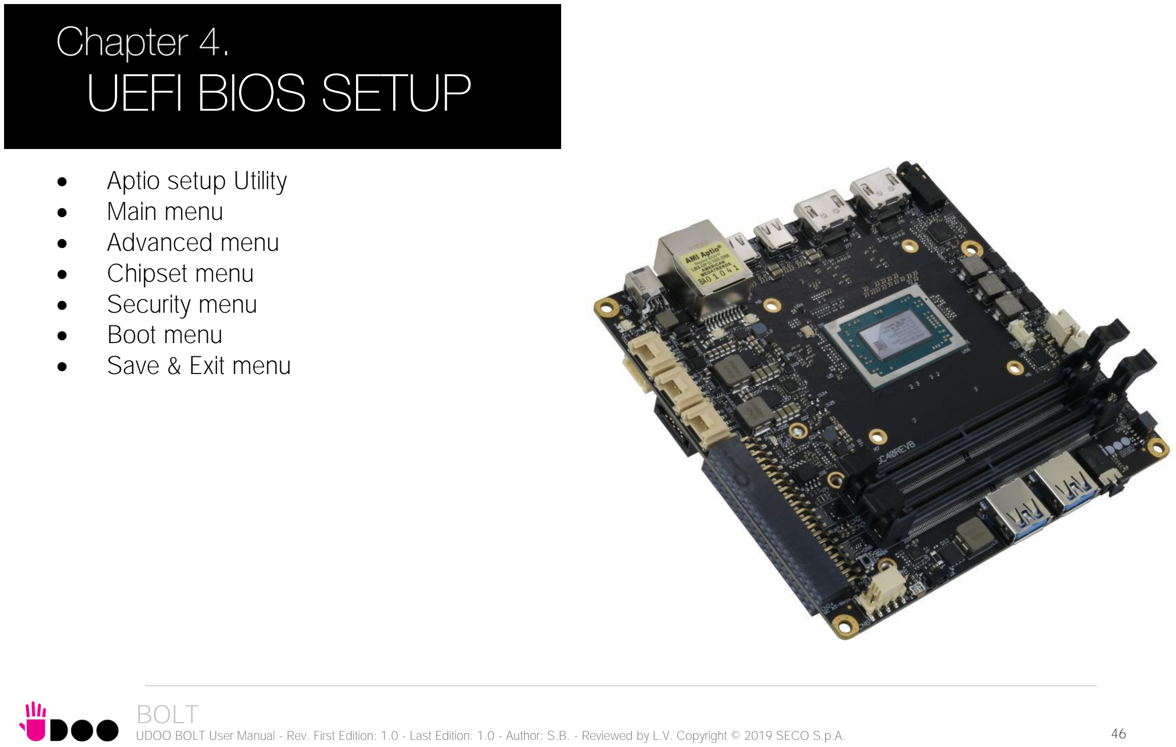
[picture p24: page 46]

UDOO BOLT User Manual - Rev. First Edition: 1.0 - Last Edition: 1.0 - Author: S.B. - Reviewed by L.V. Copyright © 2019 SECO S.p.A. | 46

## - Aptio setup Utility - Main menu - Advanced menu - Chipset menu - Security menu - Boot menu - Save & Exit menu

UDOO BOLT User Manual - Rev. First Edition: 1.0 - Last Edition: 1.0 - Author: S.B. - Reviewed by L.V. Copyright © 2019 SECO S.p.A. | 47

## 4.1 Aptio setup Utility

Basic setup of the board can be done using American Megatrends, Inc. “Aptio Setup Utility”, that is stored inside an onboard SPI Serial Flash.
It is possible to access to Aptio Setup Utility by pressing the <ESC> key after System power up, during POST phase. On the splash screen that will appear, select “SCU” icon.
On each menu page, on left frame are shown all the options that can be configured.
Grayed-out options are only for information and cannot be configured.
Only options written in blue can be configured. Selected options are highlighted in white. Right frame shows the key legend.
KEY LEGEND:
← / → | Navigate between various setup screens (Main, Advanced, Security, Power, Boot...)
↑ / ↓ | Select a setup item or a submenu
+ / - | + and - keys allows to change the field value of highlighted menu item
<F1> | The <F1> key allows displaying the General Help screen.
<F2> | Previous Values
<F3> | <F3> key allows loading Optimised Defaults for the board. After pressing <F3> BIOS Setup utility will request for a confirmation, before loading such
default values. By pressing <ESC> key, this function will be aborted
<F4> | <F4> key allows save any changes made and exit Setup. After pressing <F10> key, BIOS Setup utility will request for a confirmation, before saving
and exiting. By pressing <ESC> key, this function will be aborted
<ESC> | <Esc> key allows discarding any changes made and exit the Setup. After pressing <ESC> key, BIOS Setup utility will request for a confirmation,
before discarding the changes. By pressing <Cancel> key, this function will be aborted
<ENTER> <Enter> key allows to display or change the setup option listed for any setup item. The <Enter> key can also allow displaying the setup sub-screens.

It is possible to reset the UEFI BIOS Setup to Factory Defaults by using the dedicated switch available on module. Please check par. 3.3.15.

UDOO BOLT User Manual - Rev. First Edition: 1.0 - Last Edition: 1.0 - Author: S.B. - Reviewed by L.V. Copyright © 2019 SECO S.p.A. | 48

## 4.2 Main menu

When entering the Setup Utility, the first screen shown is the Main setup screen. It is always possible to return to the Main setup screen by selecting the Main tab. In this screen, are shown details regarding BIOS version, Processor type, Bus Speed and memory configuration.
Only two options can be configured:
4.2.1 System Time / System Date

Use this option to change the system time and date. Highlight System Time or System Date using the <Arrow> keys. Enter new values directly through the keyboard, or using + / - keys to increase / reduce displayed values. Press the <Enter> key to move between fields. The date must be entered in MM/DD/YY format. The time is entered in HH:MM:SS format.
Note: The time is in 24-hour format. For example, 5:30 A.M. appears as 05:30:00, and 5:30 P.M. as 17:30:00.
The system date is in the format mm/dd/yyyy.

UDOO BOLT User Manual - Rev. First Edition: 1.0 - Last Edition: 1.0 - Author: S.B. - Reviewed by L.V. Copyright © 2019 SECO S.p.A. | 49

## 4.3 Advanced menu

Menu Item | Options | Description
AMD CBS | See submenu | AMD CBS Setup Page
AMD PBS | See submenu | AMD PBS Setup Page
RAM Disk Configuration | See submenu | Add/remove RAM disks
Battery Failure manager | See submenu | Sets the action to be performed in case of battery failure
Trusted Computing | See submenu | Trusted Computing Settings
ACPI Settings | See submenu | System ACPI parameters
SATA presence | See submenu | SATA devices Configuration
DXIO Settings | See submenu | PEG, PCIE and DDI Lanes configuration
S5 RTC Wake Settings | See submenu | Enable System to wake from S5 using RTC alarm
CPU Configuration | See submenu | CPU Configuration Parameters
AMI Graphic Output Protocol Policy | See submenu | User Selected Monitor Output by Graphic Output protocol
PCI Subsystem Settings | See submenu | PCI Subsystem Settings
Network Stack Configuration | See submenu | Network Stack Settings
CSM Configuration | See submenu | Compatibility Support Module (CSM) Configuration: Enable/Disable, Option ROM execution Settings, etc...
NVMe Configuration | See submenu | NVMe Device Options Settings
SDIO Configuration | See submenu | SDIO Configuration Parameters
USB Configuration | See submenu | USB Configuration Parameters
Main Thermal Configuration | See submenu | Main thermal Configuration
SMBIOS Information | See submenu | SMBIOS Information
Embedded Controller | See submenu | Embedded Controller Firmware Information
USB-C Port Controller | See submenu | USB-C Port Controller Information

UDOO BOLT User Manual - Rev. First Edition: 1.0 - Last Edition: 1.0 - Author: S.B. - Reviewed by L.V. Copyright © 2019 SECO S.p.A. | 50
4.3.1 | AMD CBS submenu
4.3.1.1 | Zen Common Options submenu

4.3.1.1.1 Core/Thread Enablement submenu
By disabling cores/threads, the state S3 will not be supported anymore. Therefore it is requested to agree with the disabling before going in the related submenu

4.3.1.1.1.1 Agree submenu

4.3.1.2 | UMC Common Options submenu
Menu Item | Options | Description
Zen Common options | See submenu | Zen Configuration Options
UMC Common options | See submenu | UMC Configuration options
NBIO Common options | See submenu | NorthBridge IO Configuration Options
FCH Common options | See submenu | Firmware Controller Hub Configuration options
Menu Item | Options | Description
Core/Thread Enablement | See submenu | Allows selecting options for enabling Cores and Threads.
Menu Item | Options | Description
Disagree | Return to previous menu
Agree | See Submenu
Menu Item | Options | Description
Downcore control | One / Two / Three / Auto | Sets the number of cores to be used. Once this option has been used to remove any cores, a Power cycle is required in order for future selections to take effect,
SMTEN | Disable / Auto | Can be used to disable symmetric multithreading. To re-enable SMT, a Power Cycle is needed after selecting the ‘Auto’ option. WARNING S3 is not supported on systems where SMT is disabled.
Menu Item | Options | Description
DDR4 Common options | See submenu | DDR4 memory

UDOO BOLT User Manual - Rev. First Edition: 1.0 - Last Edition: 1.0 - Author: S.B. - Reviewed by L.V. Copyright © 2019 SECO S.p.A. | 51

4.3.1.2.1 DDR4 Common options submenu

4.3.1.2.1.1 DDR4 Timing Configuration submenu
By going further in this menu, it is possible to enable the overclocking of the processor. Since overclocking can damage or shorten the life of the processor and other components, resulting in long term system instabilities even after returning to factory default settings. To set, it is required to accept that technical support from the manufacturer can no longer be provided

4.3.1.2.1.1.1 I Accept submenu

4.3.1.3 | NBIO Common Options submenu
Menu Item | Options | Description
DDR4 Timing Configuration | See Submenu
Menu Item | Options | Description
I Decline | Return to previous menu
I Accept | See Submenu
Menu Item | Options | Description
Overclock | Auto Enabled | By enabling this option, it will be possible to configure individually a list of memory parameters for the overclocking (the complete list is not reported here)
Menu Item | Options | Description
GFX Configuration | See submenu | GFX Configuration options
PCIe Configuration | See submenu | PCI-e Speed Power Policy options
| 12W POR Configuration/ | Allows selecting the Power Scheme configuration for the CPU.
| 15W POR Configuration/ | Warning: by selecting a precise configuration, may cause the system to hang, as some System
| 25W POR Configuration | Configurations may not be supported by your OPN.

System Configuration

Audio Codecs | Enabled Disabled
Disable/Enable Audio Codecs input signals SDIN0

UDOO BOLT User Manual - Rev. First Edition: 1.0 - Last Edition: 1.0 - Author: S.B. - Reviewed by L.V. Copyright © 2019 SECO S.p.A. | 52

4.3.1.3.1 GFX Configuration submenu

4.3.1.3.2 PCIe Configuration submenu

4.3.1.4 | FCH Common Options submenu
Menu Item | Options | Description
Integrated Graphics Controller | Auto / Disabled / Forces | Enable Integrated Graphics Controller. If disabled, all the remaining options will disappear
UMA Mode | Auto / UMA_Specified /
UMA_Auto

Only available when Integrated Graphics Controller is set to “Forces”. Allows setting the Unified Memory Architecture (UMA) Frame Buffer Size or Display Resolution

UMA Version | Legacy / Non-Legacy /
Hybrid Secure / Auto | Only available when Integrated Graphics Controller is set to “Forces”. Sets the supported UMA compatibility.

UMA Frame Buffer Size

Auto / 256M / 384M /
512M / 768M / 1G / 2G
/ 3G / 4G / 8G / 16G

Only available when “UMA Mode” is set to UMA_Specified. Sets UMA Frame Buffer Size

Display Resolution

1920X1080 and below /
2560x1600 /
3840x2160 / Auto

Only available when “UMA Mode” is set to UMA_Auto. Sets Display Resolution

Integrated HD Audio Controller | Auto / Disabled /
Enabled | Enables or disabled integrated HD Audio Controller
Menu Item | Options | Description
| Disabled

PSPP Policy

Performance
Balanced-high
Balanced-Low
Power Saving
Auto

PCIe Speed Power policy: the processor can dynamically support the changing to the link frequency due to changes in system configuration and power policy.

Menu Item | Options | Description
SATA Configuration Options | See submenu | SATA Configuration Options

UDOO BOLT User Manual - Rev. First Edition: 1.0 - Last Edition: 1.0 - Author: S.B. - Reviewed by L.V. Copyright © 2019 SECO S.p.A. | 53

4.3.1.4.1 SATA Configuration submenu

4.3.2 | AMD PBS submenu
4.3.3 | RAM Disk Configuration submenu
4.3.3.1 | Create raw submenu
Menu Item | Options | Description
SATA Controller | Auto / Disabled /
| Enabled | Enable or Disable on-chip SATA controller
| AHCI
SATA Mode | AHCI as ID 0x7904 | Only available when SATA Controller is set to “Enabled”. Select on-chip SATA Type
Auto
RAID
Menu Item | Options | Description
AMD Firmware Version | | Opens an information page with all details about the Firmware
Primary Video Adaptor | Int. Graphics (IGD) Ext. Graphics (PEG)

Allows to select if Internal Graphics controller (IGD) or external PCI-e Graphic Controller x8 (PEG) should be used as a Primary display

Menu Item | Options | Description
Disk Memory type | Boot Service Data
| Reserved | Specifies the type o f memory to use from available memory pool in system to create a disk.
Create raw | See submenu | Create a raw RAM disk
Create from file | | Create a RAM disk from a given file (opens a File Explorer menu)
Remove selected RAM disk(s). | | Remove selected RAM disks.
Menu Item | Options | Description
Size (Hex) | | Sets the RAM disk size, which should be multiples of the RAM disk block size,
Create & Exit | | Create a new RAM disk with the given starting and ending address.
Discard & Exit | | Discard and exit.

UDOO BOLT User Manual - Rev. First Edition: 1.0 - Last Edition: 1.0 - Author: S.B. - Reviewed by L.V. Copyright © 2019 SECO S.p.A. | 54
4.3.4 | Battery Failure Manager submenu
4.3.5 | Trusted computing submenu
Menu Item | Options | Description
| | Sets the action that must be done when a backup battery failure occurs.
Battery Failure Action

None
Restore Defaults
Restore NVRAM

None: no action
Restore defaults: restore BIOS factory default, preserving the password(s) Reset NVRAM: restore all factory defaults, clearing also the password(s)
Menu Item | Options | Description
| | Enables or Disables BIOS Support for security devices. OS will not show Security Device, TCG EFI
Security Device Support | Disabled / Enabled | protocol and INT1A interface will not be available.
When disabled, all following items will disappear.
SHA-1 PCR Bank | Disabled / Enabled | Enables or Disables SHA-1 PCR Bank
SHA256 PCR Bank | Disabled / Enabled | Enables or Disables SHA256 PCR Bank
Pending operation | None
TPM Clear | change the State of Security Device.
Platform Hierarchy | Disabled / Enabled | Enable or Disable Platform Hierarchy
Storage Hierarchy | Disabled / Enabled | Enable or Disable Storage Hierarchy
Endorsement Hierarchy | Disabled / Enabled | Enable or Disable Endorsement Hierarchy
| | Select the TCG2 Spec version Support.

Schedule an operation for the Security Device. Note: your computer will reboot during restart in order to

TPM2.0 UEFI Spec Version | TCG_1_2 TCG_2
TCG_1_2 is the compatible mode for Windows 8 and Windows 10
TCG_2 supports the new TCG2 protocol and event format for Windows 10 and later
Physical Presence Spec Version | 1.2 / 1.3 | Tells the OS to support PPI Spec version 1.2 or 1.3. Note that some HCK tests might not support 1.3
| Auto | TPM 1.2 will restrict the support to TPM 1.2 devices only, TPM 2.0 will restrict the support to TPM 2.0
| TPM 1.2 | devices only, Auto will support both with the default set to TPM 2.0 devices if not found, TPM 1.2 devices
| TPM 2.0 | will be enumerated

Device Select

UDOO BOLT User Manual - Rev. First Edition: 1.0 - Last Edition: 1.0 - Author: S.B. - Reviewed by L.V. Copyright © 2019 SECO S.p.A. | 55
4.3.6 | ACPI Settings
4.3.7 | SATA presence submenu
4.3.8 | DXIO Settings submenu
4.3.8.1 | DDI Port submenu
Menu Item | Options | Description
Enable ACPI Auto Configuration | Disabled / Enabled | Enables or Disables BIOS ACPI Auto Configuration. The following menu items will appear only when this
| | menu item is Disabled
Enable Hibernation | Disabled / Enabled | Enables or disables system ability to Hybernate (OS/S4 Sleep State). This option may be not effective with
| | some OS.
ACPI Sleep State | Suspend Disabled
| S3 (Suspend to RAM) | Select the highest ACPI Sleep state the system will enter when the SUSPEND button is pressed.
Lock Legacy resources | Disabled / Enabled | Enables or Disables Lock of Legacy resources
Menu Item | Options | Description

M.2 (CN18 Key B SATA)
Standard (CN14) SATA | Shows information related to eventual devices connected to SATA ports 0 or 1.
Menu Item | Options | Description
DDI Port | See submenu | Allows enabling and configuring the single DDI ports
PEG Port | See submenu | Allows enabling and configuring the PEG port(s)
PCI-E Port | See submenu | Allows enabling and configuring the PCI-e ports
Menu Item | Options | Description

HDMI0 (CN20) State
HDMI1 (CN19) State
USB-C1 (CN9) DP State
USB-C0 (CN8) DP State

Disabled
Enabled | Enable or Disable individually the video interfaces

UDOO BOLT User Manual - Rev. First Edition: 1.0 - Last Edition: 1.0 - Author: S.B. - Reviewed by L.V. Copyright © 2019 SECO S.p.A. | 56
4.3.8.2 | PEG Port submenu
Menu Item | Options | Description
M.2 x4 (CN17 Key M) | Enabled / Disabled | Enable or disable the PEG x4 port available on M.2 Key M (NVMe) slot. When enabled, all following items will appear.

ASPM Mode Control

Disabled
L0s Entry
L1 Entry
L0s and L1 Entry
Auto

Disable or Enable PCI Express Active State Power Management

| PCIe Gen1
Link Speed | | Configures NB Root Port PCIe Link Speed, which can however be overwritten by PSPP Settings

PCIe Gen2
Max Speed
Auto

Hot Plug Mode Control

Auto
Disabled
Hotplug Basic
Hotplug Server
Hotplug Enhanced
Hotplug Inboard

PCI Express Root Port Hot Plug Mode Control

Compliance Mode | Enabled / Disabled | If enabled, forces the port into Compliance mode.

UDOO BOLT User Manual - Rev. First Edition: 1.0 - Last Edition: 1.0 - Author: S.B. - Reviewed by L.V. Copyright © 2019 SECO S.p.A. | 57
4.3.8.3 | PCI-E Port submenu
4.3.9 | S5 RTC Wake Settings submenu
Menu Item | Options | Description

M.2 x2 (CN18 Key B)
M.2 x1 (CN16 Key E)
Internal LAN
Enabled / Disabled | Enable or disable each single PCIE port . When enabled, all following items will appear.

ASPM Mode Control

Disabled
L0s Entry
L1 Entry
L0s and L1 Entry
Auto

Disable or Enable PCI Express Active State Power Management

| PCIe Gen1
Link Speed | | Configures NB Root Port PCIe Link Speed, which can however be overwritten by PSPP Settings

PCIe Gen2
Max Speed
Auto

Hot Plug Mode Control

Auto
Disabled
Hotplug Basic
Hotplug Server
Hotplug Enhanced
Hotplug Inboard

PCI Express Root Port Hot Plug Mode Control

Compliance Mode | Enabled / Disabled | If enabled, forces the port into Compliance mode.
Menu Item | Options | Description
| Disabled
Wake system from S5
By Every Day
By Day of Month

Enables or disables System Wake on Alarm event.
The following menu items will appear only when this voice is not set to Disabled
Wake up hour | 0..23 | Sets the wake up hour in 0..23 format (i.e.,3 means 3am, 15 means 3pm)
Wake up minute | 0..59 | Sets the wake up minute
Wake up second | 0..59 | Sets the wake up second
| | This item is available only when “Wake system from S5” is set to “By Day of Month”.
Day of Month | 1..31
Sets the day of month for Wake on Alarm event. Valid range s from 1 to 31, error checking will be done against month/day/year combinations that are not valid.

UDOO BOLT User Manual - Rev. First Edition: 1.0 - Last Edition: 1.0 - Author: S.B. - Reviewed by L.V. Copyright © 2019 SECO S.p.A. | 58

4.3.10 CPU configuration submenu

PPC Adjustment | PState 0 / PState 1 /
PState 2 | Provide to adjust startup P-state level
NX Mode | Enabled / Disabled | Enables or Disables No-execute Page Protection Function
SVM Mode | Enabled / Disabled | Enables or disables CPU Virtualization
Node 0 Information | | Opens an information page with the Memory Information details related to Node 0

Only Available when PSS Support is enabled

4.3.11 AMI graphic Output Protocol Policy submenu

4.3.12 PCI Subsystem Settings submenu

Menu Item | Options | Description
PSS Support | Enabled / Disabled | Enable/disable the generation of ACPU _PCC, _PSS and _PCT objects
Menu Item | Options | Description
| List of available /
Output Select
connected module’s
video interfaces
Menu Item | Options | Description
Above 4G Decoding | Disabled / Enabled | Globally Enables or Disables 64-bit capable Devices to be decoded in Address Space above 4GB (only if system supports 64-bit PCI Decoding).
SR-IOV Support | Disabled / Enabled | If system has SR-IOV capable PCIe Devices, this option Enables or Disables Single Root IO Virtualization Support.
BME DMA Mitigation | Disabled / Enabled | Re-enable Bus Master Attribute disabled during PCI enumeration for PCI Bridges after SMM has been locked

UDOO BOLT User Manual - Rev. First Edition: 1.0 - Last Edition: 1.0 - Author: S.B. - Reviewed by L.V. Copyright © 2019 SECO S.p.A. | 59

4.3.13 Network Stack configuration submenu

Menu Item | Options | Description
Network Stack | Enabled / Disabled | Enables or disables UEFI Network Stack. When enabled, following menu items will appear
Ipv4 PXE Support | Enabled / Disabled | Enables or disables IPV4 PXE Boot Support. If disabled, IPV4 PXE boot option will not be created
Ipv4 HTTP Support | Enabled / Disabled | Enables or disables IPV4 HTTP Boot Support. If disabled, IPV4 HTTP boot option will not be created
Ipv6 PXE Support | Enabled / Disabled | Enables or disables IPV6 PXE Boot Support. If disabled, Ipv6 PXE boot option will not be created
Ipv6 HTTP Support | Enabled / Disabled | Enables or disables IPV6 HTTP Boot Support. If disabled, Ipv6 HTTP boot option will not be created
IPSEC certificate | Enabled / Disabled | Support to Enable/Disable IPSEC certificate for Ikev.
PXE boot wait time | [0..5] | Wait time to press ESC key to abort the PXE boot
Media detect count | [1..50] | Number of times that the presence of media will be checked

UDOO BOLT User Manual - Rev. First Edition: 1.0 - Last Edition: 1.0 - Author: S.B. - Reviewed by L.V. Copyright © 2019 SECO S.p.A. | 60

4.3.14 CSM configuration submenu

4.3.15 NVMe configuration submenu

NVMe Device Options Settings, depend on NVMe Devices found in the system.

Menu Item | Options | Description
CSM Support | Enabled / Disabled | Enables or disables the Compatibility Support Module (CSM) Support. When enabled, the following menu items will appear
GateA20 Active | Upon Request
Always | Always: do not allow disabling GateA20; this option is useful when any RT code is executed above 1MB.
| | BIOS Reaction on INT19 trapping by Option ROM:

Upon Request: GateA20 can be disabled using BIOS services,

INT19 Trap Response | Immediate Postponed
IMMEDIATE - execute the trap right away;
POSTPONED - execute the trap during legacy boot
| UEFI and Legacy
Boot option filter | | This option controls Legacy / UEFI ROMs priority
Legacy only
UEFI only
| Do not launch
Network | | Controls the execution of UEFI and Legacy PXE OpROM
UEFI
Legacy
| Do not launch
Storage | | Controls the execution of UEFI and Legacy Storage OpROM
UEFI
Legacy
| Do not launch
Video | | Controls the execution of UEFI and Legacy Video OpROM
UEFI
Legacy
| Do not launch
Other PCI devices | | Determines the OpROM execution policy for devices other than Network, Storage and Video
UEFI
Legacy

UDOO BOLT User Manual - Rev. First Edition: 1.0 - Last Edition: 1.0 - Author: S.B. - Reviewed by L.V. Copyright © 2019 SECO S.p.A. | 61

4.3.16 SDIO configuration submenu

4.3.17 USB configuration submenu

Menu Item | Options | Description
| Auto
SDIO Access Mode | ADMA
SDMA
PIO

Auto option: Access to SD Device in DMA Mode, if the controller supports it, otherwise in PIO Mode. DMA option: Access the SD Device in DMA mode only.
PIO option: Access the SD Device in PIOmode only.

MMC Name and capacity

Auto
Floppy
Forced FDD
Hard Disk

Mass storage device emulation type.
With ‘Auto’, enumerates devices less than 530MB as Floppies.
Forced FDD option can be used to force HDD formatted rive to boot as a FDD.
Menu Item | Options | Description
Legacy USB Support | Enabled / Disabled /
| Auto | Enables Legacy USB Support. AUTO Option disables legacy support if no USB devices are connected.
| | DISABLE option will keep USB devices available only for EFI applications.
XHCI hand-off | Enabled/ Disabled | This is a workaround for OSes without XHCI hand-off support. The XHCI ownership change should be
| | claimed by XHCI driver.
USB Mass Storage Driver Support | Enabled/ Disabled | Enables or disables USB Mass Storage Driver Support
Port 60/64 Emulation | Enabled/ Disabled | Enables or disables I/O port 60h/64h emulation support. This should be enabled for the complete USB
| | keyboard legacy support for non-USB aware OSes.
USB Transfer time-out | 1 sec / 5 sec / 10 sec /
| 20 sec | Sets the time-out value for Control, Bulk and Interrupt transfers
Device reset time-out | 10 sec / 20 sec / 30
| sec / 40 sec | USB mass storage device Start Unit command time-out
Device power-up delay | Auto / Manual | Sets the maximum time that the device will take before it properly reports itself to the Host controller. ‘Auto’
| | uses the default vale (for a Root port it is 100ms, for a Hub port the delay is taken from the Hub descriptor).
Device power-up delay in seconds | [1..40] | Delay range in seconds, in one second increment

UDOO BOLT User Manual - Rev. First Edition: 1.0 - Last Edition: 1.0 - Author: S.B. - Reviewed by L.V. Copyright © 2019 SECO S.p.A. | 62

4.3.18 Main Thermal Configuration submenu

4.3.19 SMBIOS Information

Display only screen, shows information about the module and the Carrier board.
4.3.20 Embedded Controller

Display only screen, shows information about the embedded controller firmware parameters. 4.3.21 USB-C Port Controller

Display only screen, shows information about the USB-C port controller firmware.

Menu Item | Options | Description
| | This value controls the temperature of the ACPI Passive Trip Point - the point in which the OS will begin
Passive Cooling Temperature (°C) | 75 / 80 / 85 / 90
lowering the CPU speed. Allowed range is from 75 to 90, where values above Critical Temperature means Disabled.

UDOO BOLT User Manual - Rev. First Edition: 1.0 - Last Edition: 1.0 - Author: S.B. - Reviewed by L.V. Copyright © 2019 SECO S.p.A. | 63

## 4.4 Chipset menu

4.4.1 South Bridge Configuration submenu

4.4.1.1 SB USB Configuration submenu

4.4.2 | North Bridge Configuration submenu
Menu Item | Options | Description
South Bridge | See Submenu | South Bridge Parameters
North Bridge | See Submenu | North Bridge Parameters
Menu Item | Options | Description
SB USB Configuration | See submenu | USB configuration Settings
Menu Item | Options | Description

USB-C0 (CN8) USB state
Front Panel USB0 (CN21)
Front Panel USB0 (CN22)
USB-C0 (CN9) USB state
M.2 x1 (CN16 Key E) USB State Arduino USB state
Enabled / Disabled | Enables or Disables every USB Port
Menu Item | Options | Description
Memory Configuration | See submenu | Memory configuration parameters
Socket 0 Configuration | | By selecting this item, an information screen with all information related to the memory module plugged in
Socket 1 Configuration | | Socket #x will appear

UDOO BOLT User Manual - Rev. First Edition: 1.0 - Last Edition: 1.0 - Author: S.B. - Reviewed by L.V. Copyright © 2019 SECO S.p.A. | 64

4.4.2.1 Memory configuration submenu

Menu Item | Options | Description
| Auto / 1333MHz /
Memory Clock | | This option allows the user to select different memory clock values. Default value is 800MHz.

1600MHz / 1866MHz /
2133MHz / 2400MHz
Bank Interleaving | Enabled/ Disabled | Enables or disables Bank Interleaving.
Channel Interleaving | Enabled/ Disabled | Enables or disables Channel Interleaving.
Memory Clear | Enabled/ Disabled | Enables or disables memory clear function.

UDOO BOLT User Manual - Rev. First Edition: 1.0 - Last Edition: 1.0 - Author: S.B. - Reviewed by L.V. Copyright © 2019 SECO S.p.A. | 65
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

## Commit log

2020-10-03 CAD models
    [battpack.FCStd, bottom.FCStd]
2020-10-03 battery holders for the batterys
    [battpack.FCStd]
2020-10-03 Update sheet -- remove old/unused pages, update input, realize that screen won't work
    [Laptop_build.xlsx]
2020-10-03 More sheet updates
    [Laptop_build.xlsx]
2020-10-03 Dont remember what I changed.. rounded corners?
    [bottom.FCStd]
2020-10-03 Trim battery packs holders to accomodate lengthwise cabling
    [battpack.FCStd]
2020-10-04 added files for TMP36 and FQP30NO6L MOSFET Transistor
2020-10-07 Add fans and other small electronic bits
    [Laptop_build.xlsx]
2020-10-07 Punch a bunch of holes in the bottom of the case for cooling exhaust
    [bottom.FCStd]
2020-10-12 Add temporary Bolt frame so I can reclaim some desk space
    [caseless-bolt-holder.FCStd]
2020-10-12 Update link for ethernet port that went unavail
    [Laptop_build.xlsx]
2020-10-15 Front-left case section
    [battpack.stl, bottomcase-front-left.FCStd]
2020-10-15 Add screwhole to front left case
    [bottomcase-front-left.FCStd]
2020-10-18 Start writing down important dimensions of parts
    [parts-dimensions.ods]
2020-10-18 Add numpad power draw
    .25 AMPs?? WTF??
    [Laptop_build.xlsx]
2020-11-08 Casing hold-together T's and bottom-front-right case outline
    [bottomcase-front-left.FCStd, bottomcase-front-right.FCStd]
2020-11-08 Remote battery pack .stl file
    [battpack.stl]
2020-11-09 bottom-front-right bolt screwhold, battery cover, and T-joints
    [bottomcase-front-left.FCStd, bottomcase-front-right.FCStd]
2020-11-11 Add KVM bottom-left mounting hole
    [bottomcase-front-left.FCStd]
2020-11-11 Second mounting hole (I forgot it went on the front left too)
    [bottomcase-front-left.FCStd]
2020-11-12 Back left bottom case
    [bottomcase-back-left.FCStd, bottomcase-front-right.FCStd]
2020-11-12 Figured out how to do multi-partsgit add bottom-v2.FCStd
    [bottom-v2.FCStd]
2020-11-12 Remove old, now-unused single-part files
    [bottomcase-back-left.FCStd, bottomcase-front-left.FCStd, bottomcase-front-right.FCStd]
2020-11-12 Back right corner and complete lateral joints
    [bottom-v2.FCStd]
2020-11-12 Finish Bolt screwholes
    I'm not convinced these are in the right places, but I guess I'll find out!
    [bottom-v2.FCStd]
2020-11-12 Dunno what changed!
    [bottom-v2.FCStd]
2020-11-15 Back-of-case fan holes
    [bottom-v2.FCStd]
2020-11-28 Right-side external USB hub
    [bottom-v2.FCStd]
2020-11-28 Reinforce back wall of case (for mounting top part)
    [bottom-v2.FCStd, parts-dimensions.ods]
2020-11-29 Bolt cooling holes
    [bottom-v2.FCStd]
2020-12-24 Learned how to label things
    Also added pin-holes for vertical hold pins for BFL-BBL and BFL-BFR
2020-12-24 Other half of prev commit, and vertical hold pin
    [vert-hold-pin-1.FCStd]
2020-12-24 Battery pack lid
    Now featuring battery hold-in-place so you don't have to glue them down!
    [battpack.FCStd]
2020-12-24 Battery labelling
    No idea what I changed on the case but Git thinks something did...
    [battpack.FCStd]
2020-12-25 Add T-joint strength test model
    For printing and breaking to see how strong it is
    [tjoint-strength-test.FCStd]
2020-12-25 Vertical hold pin for BFR-BBR joint
    Not happy with this one, but it should work...
    [vert-hold-pin-2.FCStd]
2021-01-01 ??? change on battpack
    [battpack.FCStd]
2021-01-01 Add STL files of new parts
    To be removed on merge; allows for in-browser previewing without having to download software
    [battpack.FCStd, battpack.stl, bottom-v2.stl]
2021-01-02 Remove STL files post-merge
    As promised!
    [battpack.stl, bottom-v2.stl]
2021-01-02 A programmer's attempt at a battery calculator
    [Laptop_build.xlsx]
2021-01-02 Punch a hole in the battery pack for an XT60
    Battery pack gets the male end
    [battpack.FCStd]
2021-01-06 Not sure what changed :(
    [Laptop_build.xlsx, battpack.FCStd]
2021-01-17 Remove old bottom case; rename v2 to case.FCStd
    [bottom.FCStd]
2021-01-17 XT60 connector for L batt
2021-01-19 Add version case .obj file
    [case.obj]
